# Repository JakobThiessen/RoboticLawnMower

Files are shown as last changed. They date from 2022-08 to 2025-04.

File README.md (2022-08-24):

# RoboticLawnMower
Rasenmähroboter in Eigenbau

## Konzept



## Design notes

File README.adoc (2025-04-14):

= RoboticLawnMower
:TOC:

== Projektbeschreibung
Rasenmähroboter in Eigenbau

== Konzept

static

== Projektübersicht

== Hardware
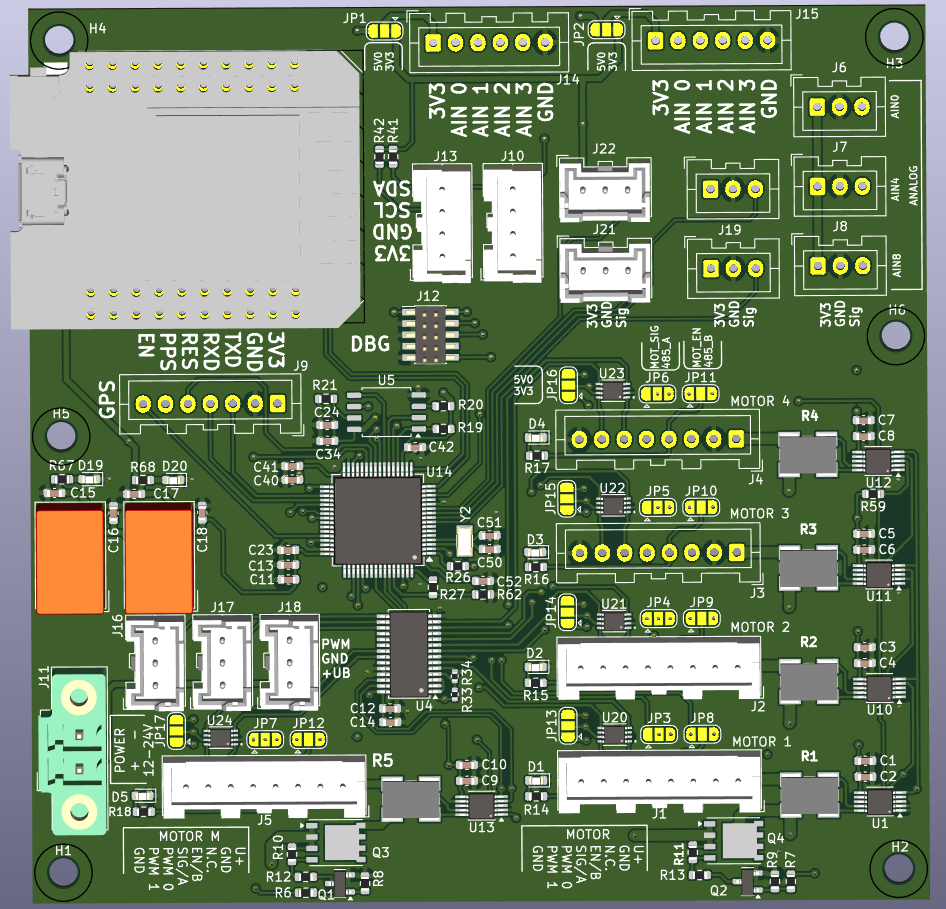
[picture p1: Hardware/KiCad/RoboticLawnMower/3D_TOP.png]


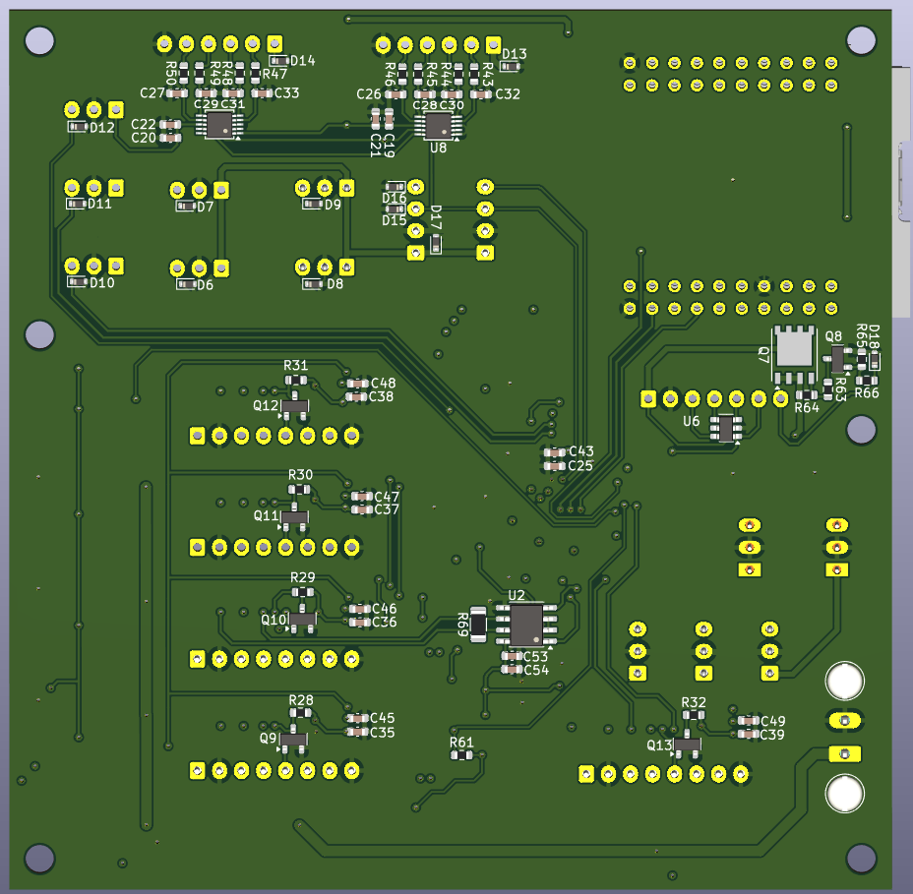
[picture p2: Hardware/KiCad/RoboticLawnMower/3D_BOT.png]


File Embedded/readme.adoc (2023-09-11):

[source,ruby]
----
static int8_t config_VL53L1(uint8_t chip_id)
{
	int8_t status = 0;
	
	  /* This function must to be called to initialize the sensor with the default setting  */
	  status = VL53L1X_SensorInit(chip_id);
	  /* Optional functions to be used to change the main ranging parameters according the application requirements to get the best ranging performances */
	  status = VL53L1X_SetDistanceMode(chip_id, 2); /* 1=short, 2=long */
	  status = VL53L1X_SetTimingBudgetInMs(chip_id, 100); /* in ms possible values [20, 50, 100, 200, 500] */
	  status = VL53L1X_SetInterMeasurementInMs(chip_id, 100); /* in ms, IM must be > = TB */
	  //  status = VL53L1X_SetOffset(chip_id,20); /* offset compensation in mm */
	  //  status = VL53L1X_SetROI(chip_id, 16, 16); /* minimum ROI 4,4 */
	  //	status = VL53L1X_CalibrateOffset(chip_id, 140, &offset); /* may take few second to perform the offset cal*/
	  //	status = VL53L1X_CalibrateXtalk(chip_id, 1000, &xtalk); /* may take few second to perform the xtalk cal */
//	  printf("VL53L1X Ultra Lite Driver Example running ...\n");
	  status = VL53L1X_StartRanging(chip_id);   /* This function has to be called to enable the ranging */	  
	  return status;
}
----

[source,c]
----
struct range_vl53l1
{
	uint16_t Distance;
	uint16_t SignalRate;
	uint16_t AmbientRate;
	uint16_t SpadNum;
	uint8_t RangeStatus;
};
----

[source,c]
int8_t getRange_VL53L1(uint8_t chip_id, struct range_vl53l1 *data)
{
	int8_t status;
	uint8_t dataReady = 0;
	while (dataReady == 0)
	{
		status = VL53L1X_CheckForDataReady(chip_id, &dataReady);
		//HAL_Delay(2);
	}
	dataReady = 0;
	status = VL53L1X_GetRangeStatus(chip_id, &data->RangeStatus);
	status = VL53L1X_GetDistance(chip_id, &data->Distance);
	status = VL53L1X_GetSignalRate(chip_id, &data->SignalRate);
	status = VL53L1X_GetAmbientRate(chip_id, &data->AmbientRate);
	status = VL53L1X_GetSpadNb(chip_id, &data->SpadNum);
	status = VL53L1X_ClearInterrupt(chip_id); /* clear interrupt has to be called to enable next interrupt*/
//	printf("%u, %u, %u, %u, %u\n", data->RangeStatus, data->Distance, data->SignalRate, data->AmbientRate, data->SpadNum);
	return status;
}
----

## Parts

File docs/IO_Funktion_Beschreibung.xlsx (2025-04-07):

 | Bezeichnung | Art | Count | Beschreibung
Sicherheit
 | NotAus | GPIO | 1 | NotAus-Schalter | GPIO
 | Kollision | GPIO | 3 | Kollision Sensor | GPIO
 | Abstandssensor | ADC | 3 | US oder TOF IR/Laser | ?
Motor
 | PCA92…. PWM | I2C - 1 | 2 | evtl. Ersatz für GPIO
 | Motor R |  |  | Motor Rechts
 | EN | GPIO | 0 | Enable Pin | GPIO PWR EN
 | Sig | Counter | 1 | Input Counter | CTR
 | V/R | GPIO | 1 | Vorwärts/Rückwärts
 | VEL | PWM | 0 | Geschwindigkeit | TIM
 | Motor L |  |  | Motor Links
 | EN | GPIO | 0 | Enable Pin | GPIO PWR EN
 | Sig | Counter | 1 | Input Counter | CTR
 | V/R | GPIO | 1 | Vorwärts/Rückwärts
 | VEL | PWM | 0 | Geschwindigkeit | TIM
 | Motor R |  |  | Motor Rechts
 | EN | GPIO |  | Enable Pin | GPIO PWR EN
 | Sig | Counter | 1 | Input Counter | CTR
 | V/R | GPIO | 1 | Vorwärts/Rückwärts
 | VEL | PWM | 0 | Geschwindigkeit | TIM
 | Motor L |  |  | Motor Links
 | EN | GPIO |  | Enable Pin | GPIO PWR EN
 | Sig | Counter | 1 | Input Counter | CTR
 | V/R | GPIO | 1 | Vorwärts/Rückwärts
 | VEL | PWM | 0 | Geschwindigkeit | TIM
 | Motor M |  |  | Motor Schneidewerk
 | EN | GPIO | 0 | Enable Pin | GPIO PWR EN
 | Sig | Counter | 1 | Input Counter | CTR
 | V/R | GPIO | 1 | Vorwärts/Rückwärts
 | VEL | PWM | 0 | Geschwindigkeit | TIM
 | INA228 | I2C - 1 |  | Strom, Spannung für Motor R
 | alarm | GPIO | 1 | Trigger level für Strom (Interrupt) | GPIO - OpenDrain
 | INA228 | I2C - 1 |  | Strom, Spannung für Motor L
 | alarm | GPIO |  | Trigger level für Strom (Interrupt)
 | INA228 | I2C - 1 |  | Strom, Spannung für Motor M
 | alarm | GPIO | 1 | Trigger level für Strom (Interrupt) | GPIO - OpenDrain
 | FET-Disable | GPIO | 1 | Motorspannung abschalten bei Fehler | GPIO
 | FET-Disable | GPIO | 1 | evtl Mähwerk abschalten | GPIO
Sensor
 | Licht | PCA92…. PWM | 1 | Licht
 | Bremslicht | PCA92…. PWM | 1 | Licht
 | Kompass | I2C - 0 | 2 | Kompass (eCompass)
 | BME280 | I2C - 0 |  | Temp, Druck, Luftfeuchtigkeit
 | BMI160 | I2C - 0 |  | Beschleunigungs- und Drehratensensor
 | Licht | I2C - 3 | 2 | Lichtsensor
 | PIR GridEye | I2C - 3 |  | 8X8 PIR sensor
 | GPS | UART 0 | 2 | GPS-Ortung
 |  |  | 1 | GPS EN
 | Schleife | ADC | 3 | Schleifen-Sensor
Komfort
 | ESP32 | UART 1 | 5 | WLAN/BT Kommunikation (Evtl. Kamera)
 | Display | I2C - 3
 | Tastatur | I2C - 3
 | Mähwerk |  |  | Höhenverstellung Mähwerk
 | FRAM | SPI | 4 | Speicher für Konfiguration / Karte
 | WS2128 | GPIO |  | Lichteffekte
 |  |  | 44
STM32H573 |  |  | 49

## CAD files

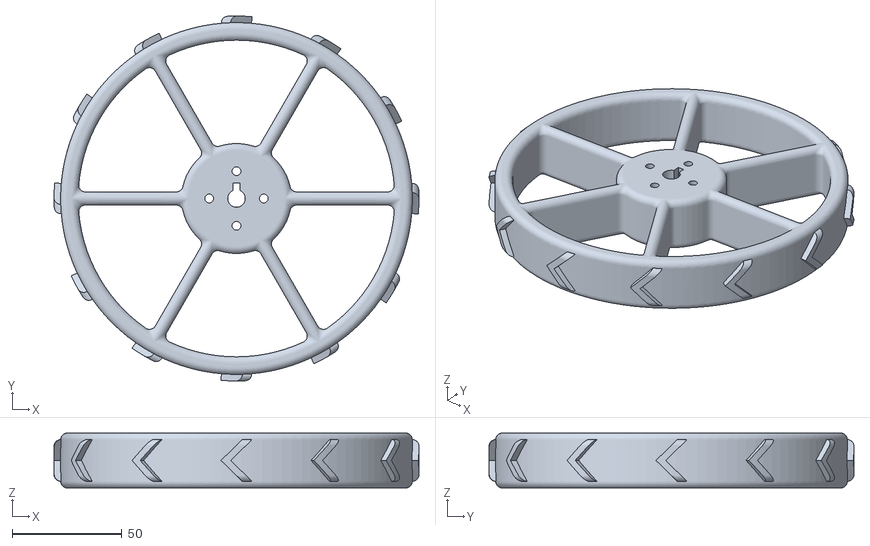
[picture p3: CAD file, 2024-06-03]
3d-models/rearWheel_6xSpoke.stl
166.0 x 166.0 x 25.0

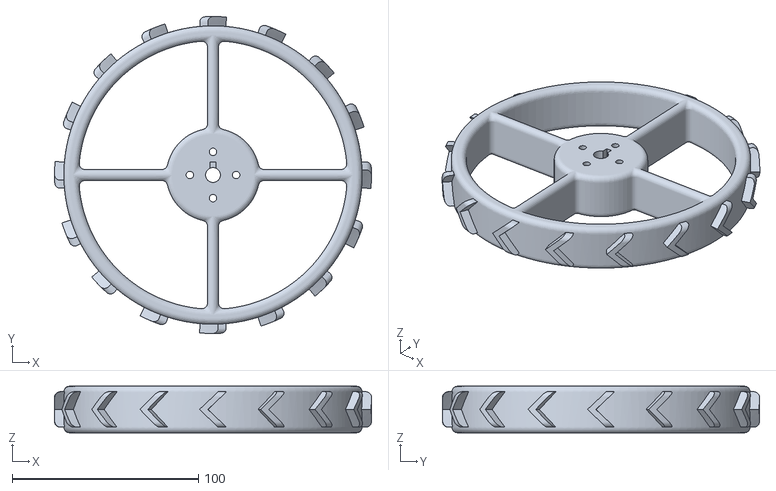
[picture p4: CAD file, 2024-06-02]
3d-models/rearWheel.stl
170.0 x 170.0 x 25.0

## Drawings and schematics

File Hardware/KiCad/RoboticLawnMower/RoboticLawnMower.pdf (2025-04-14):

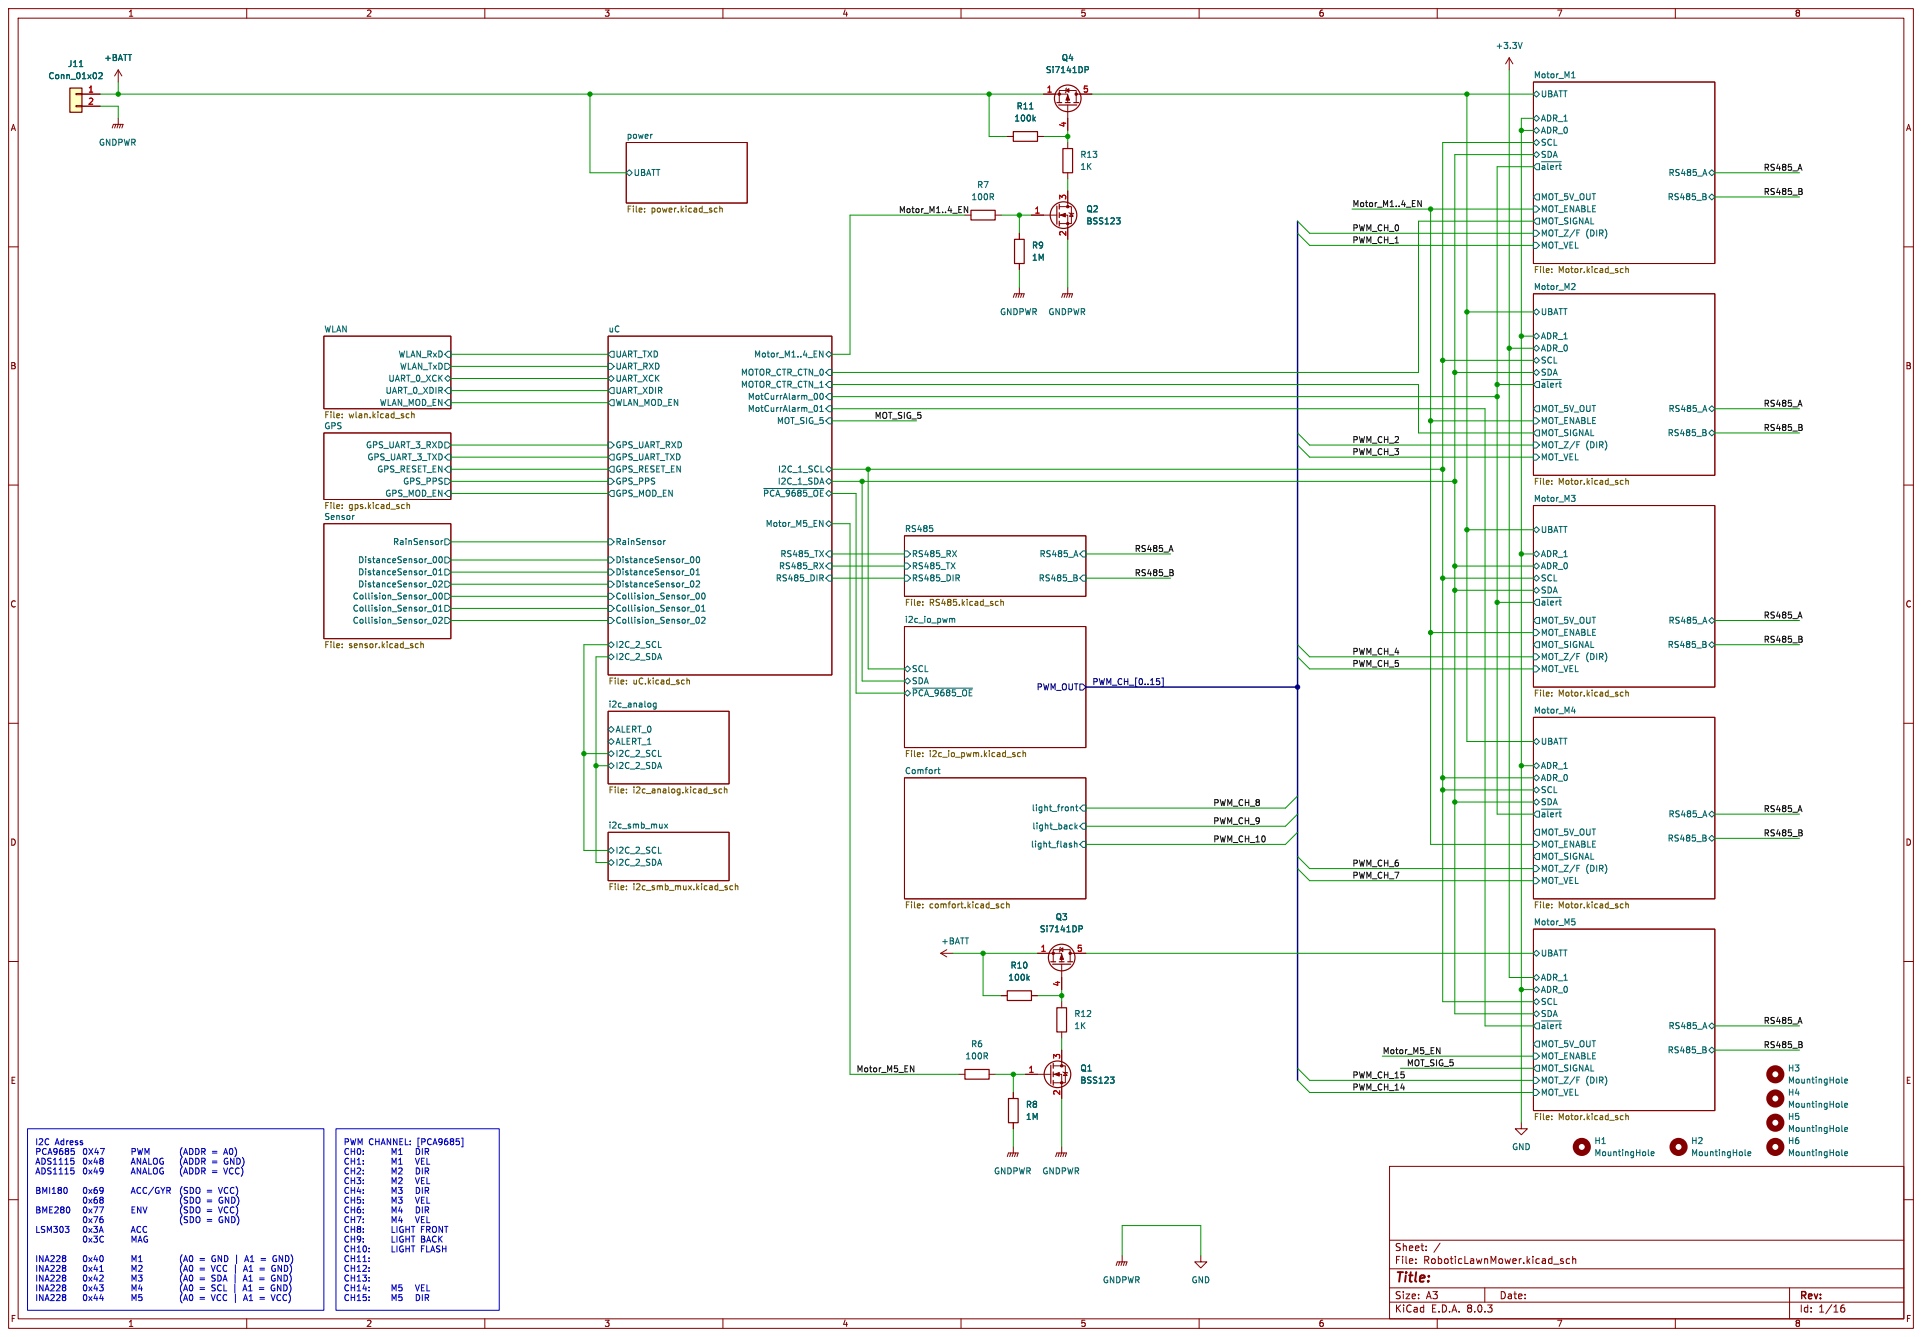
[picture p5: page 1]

PWM_CH_0 PWM_CH_1
UBATT ADR_1 MOT_VEL SCL MOT_Z/F (DIR) ADR_0 MOT_5V_OUT SDA MOT_SIGNAL MOT_ENABLE

PWM_CH_6

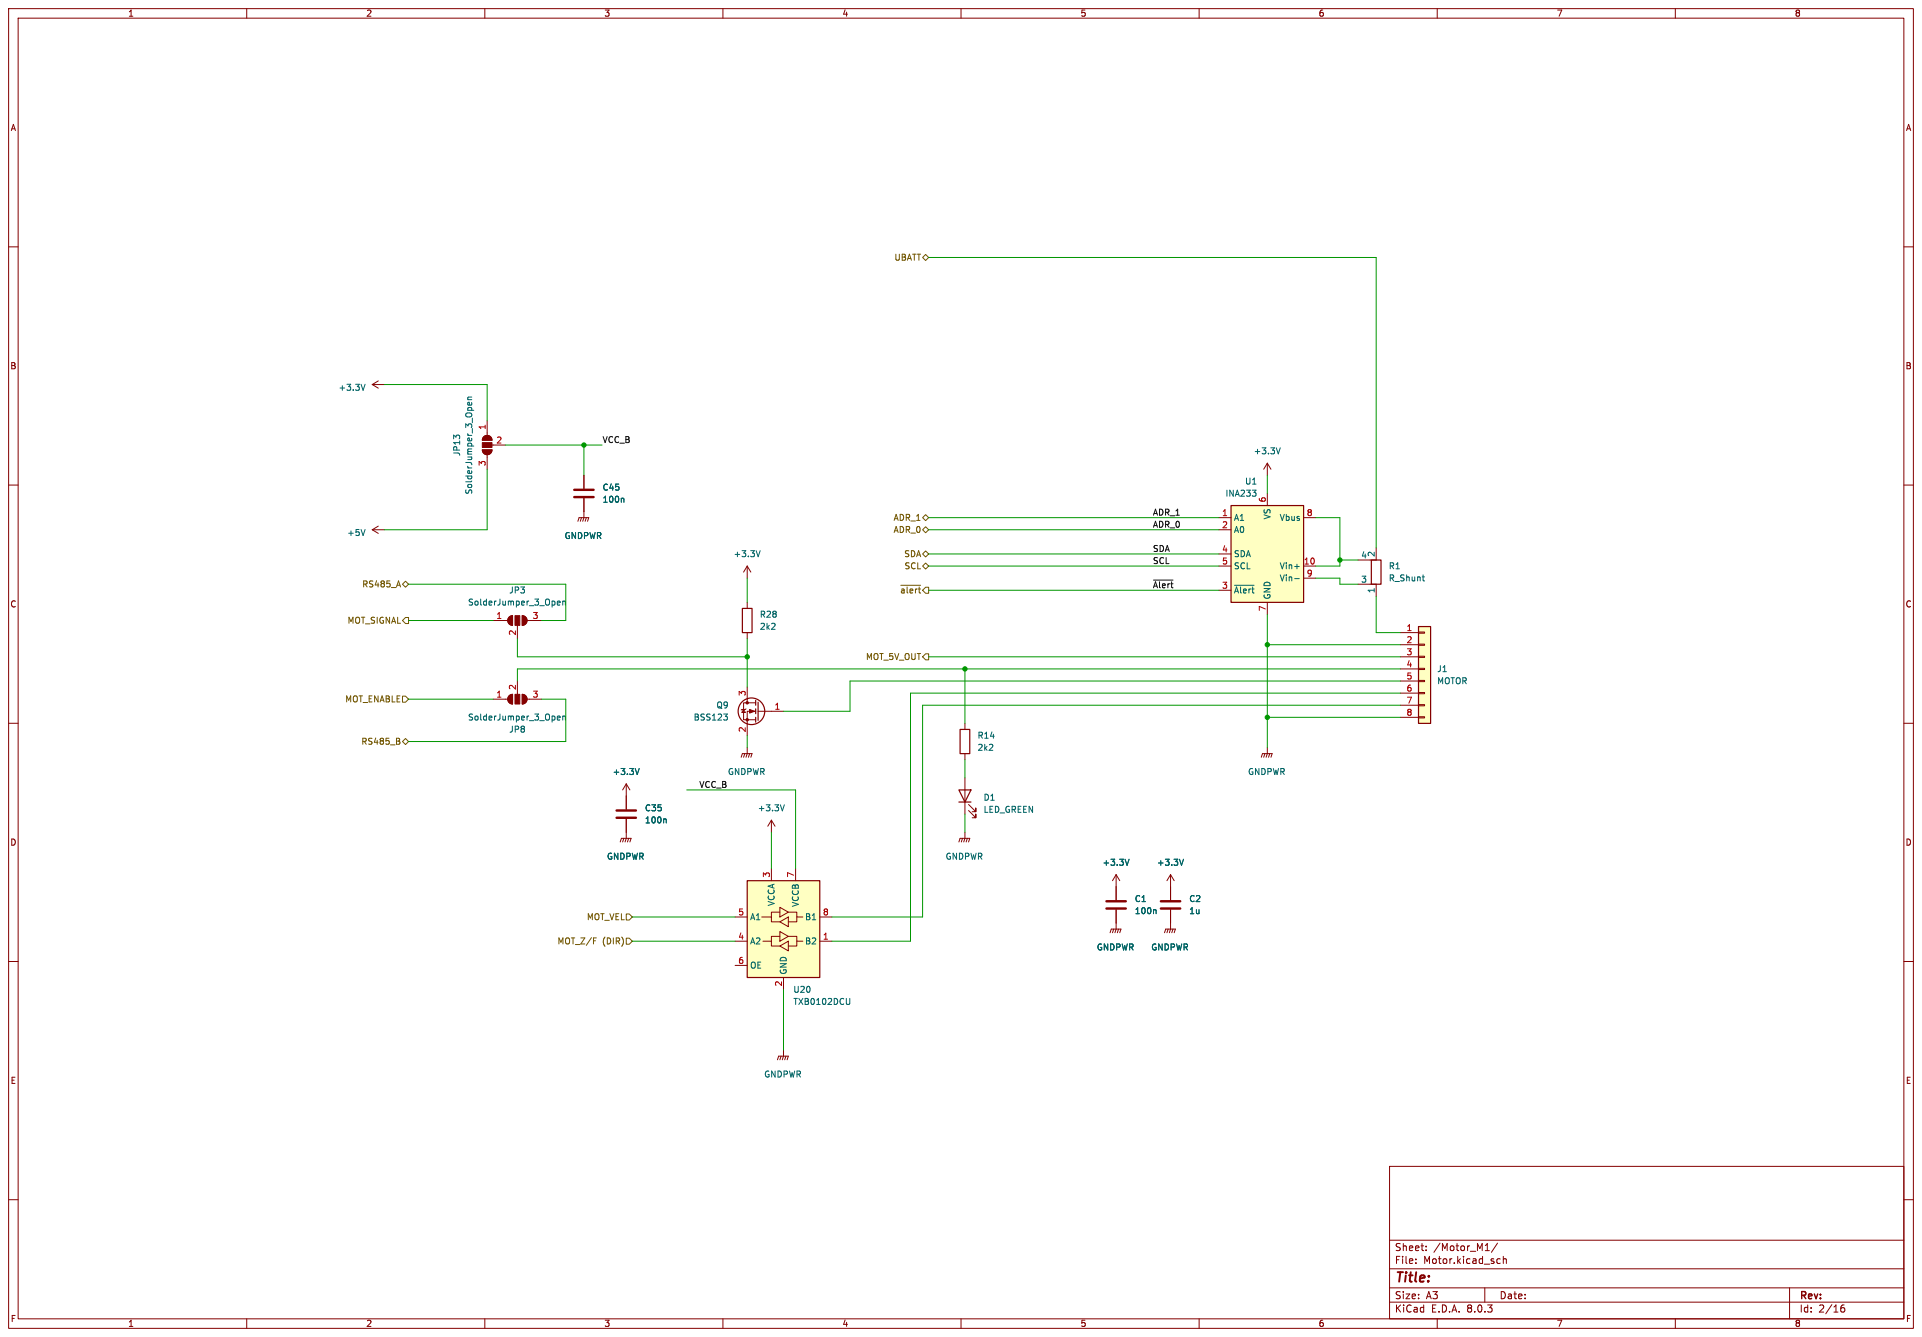
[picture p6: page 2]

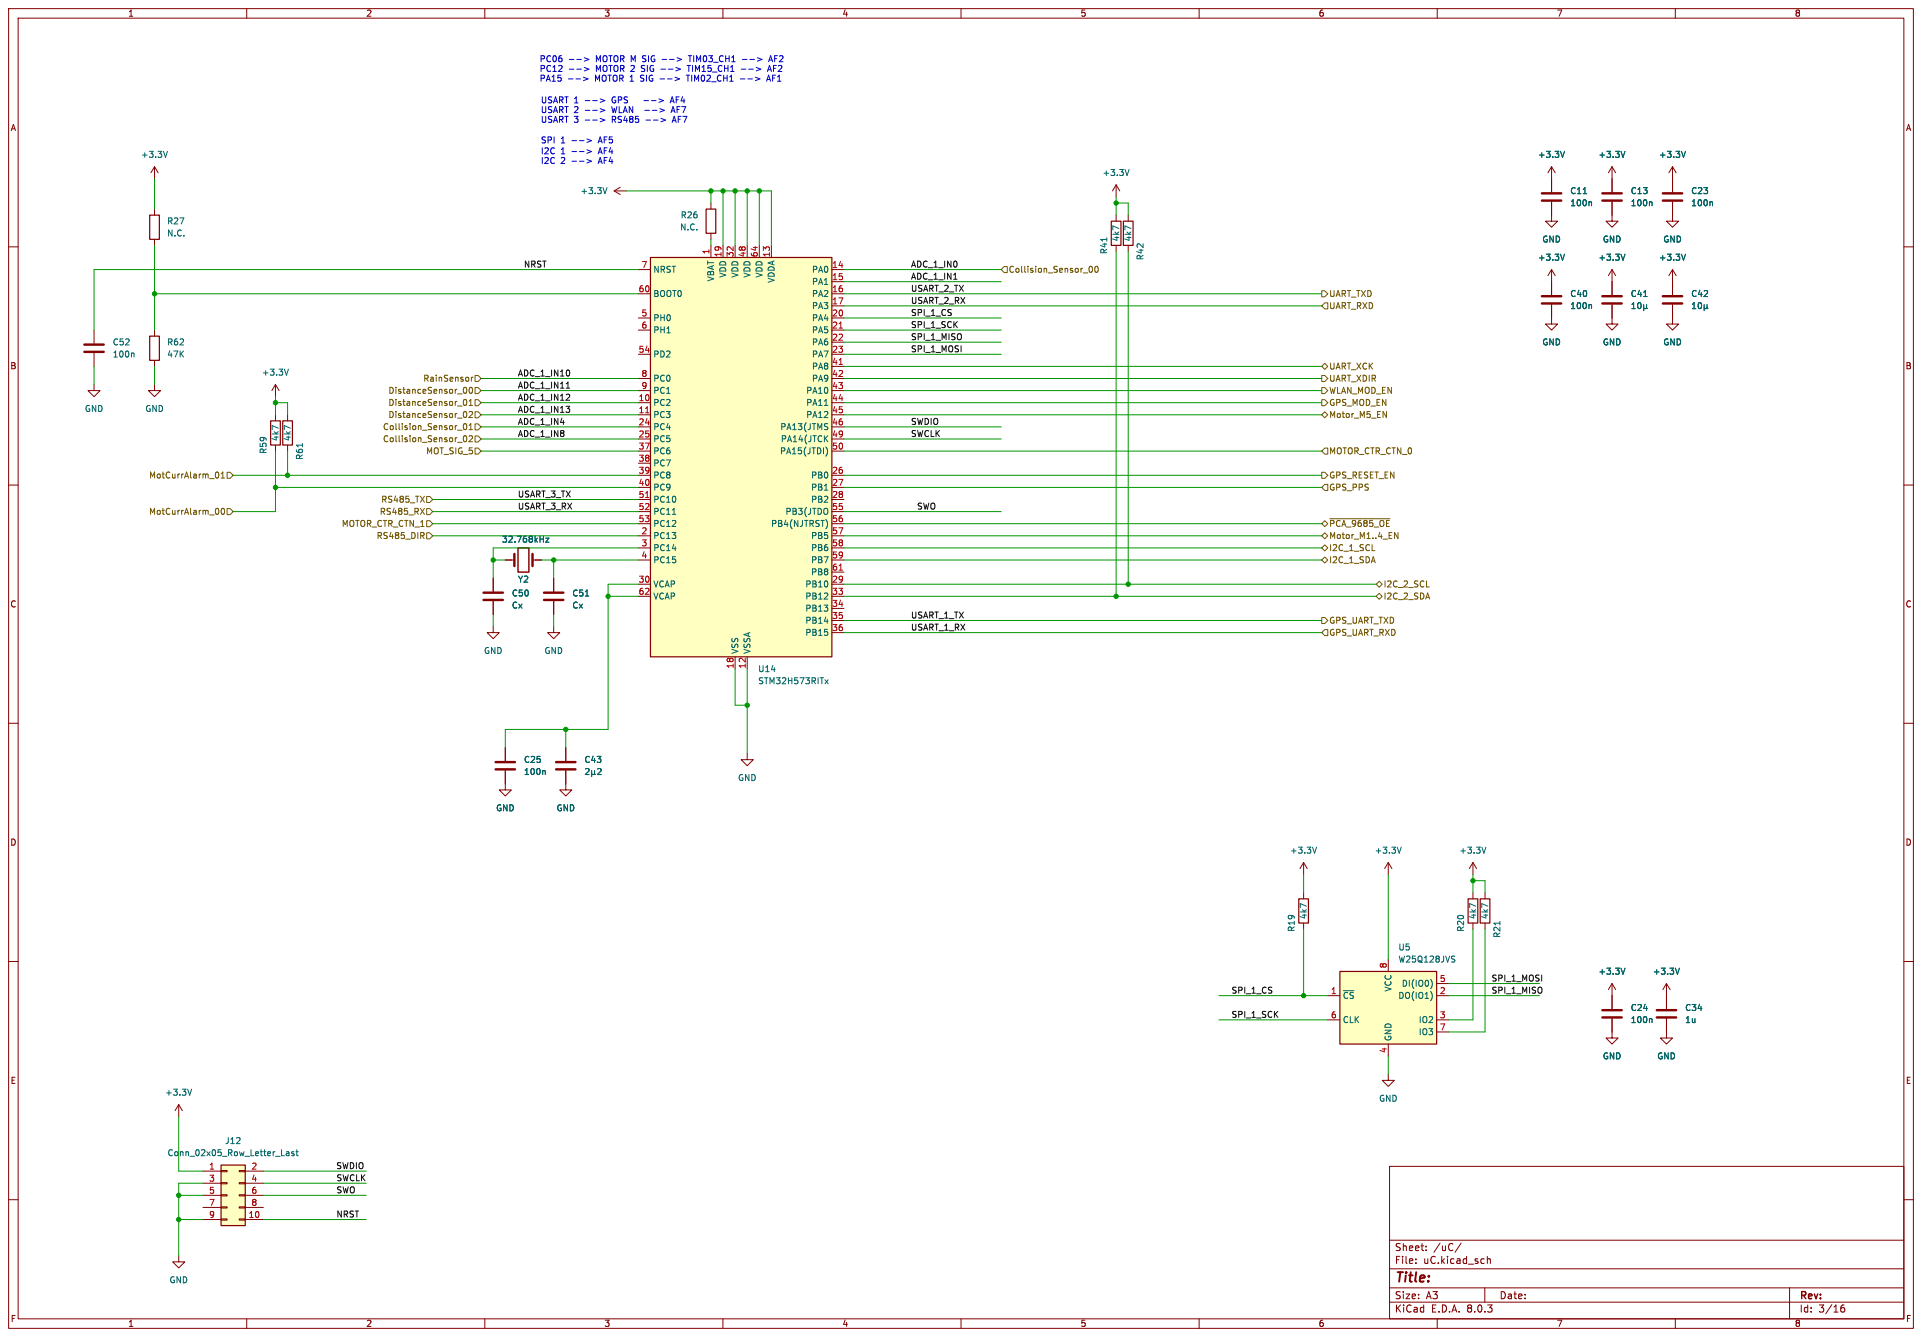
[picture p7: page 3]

1 PC2 10 PC3 11 VSSA 12 VDDA 13 PA0 14 PA1 15 PA2 16 PA3 17 VSS 18 VDD 19 PC13 2 PA4 20 PA5 21 PA6 22 PA7 23 PC4 24 PC5 25 PB0 26 PB1 27 PB2 28 PB10 29 PC14 3 VCAP 30 VDD 32 PB12 33 PB13 34 PB14 35 PB15 36 PC6 37 PC7 38 PC8 39 PC15 4 PC9 40 PA8 41 PA9 42 PA10 43 PA11 44 PA12 45 PA13(JTMS 46 VDD 48

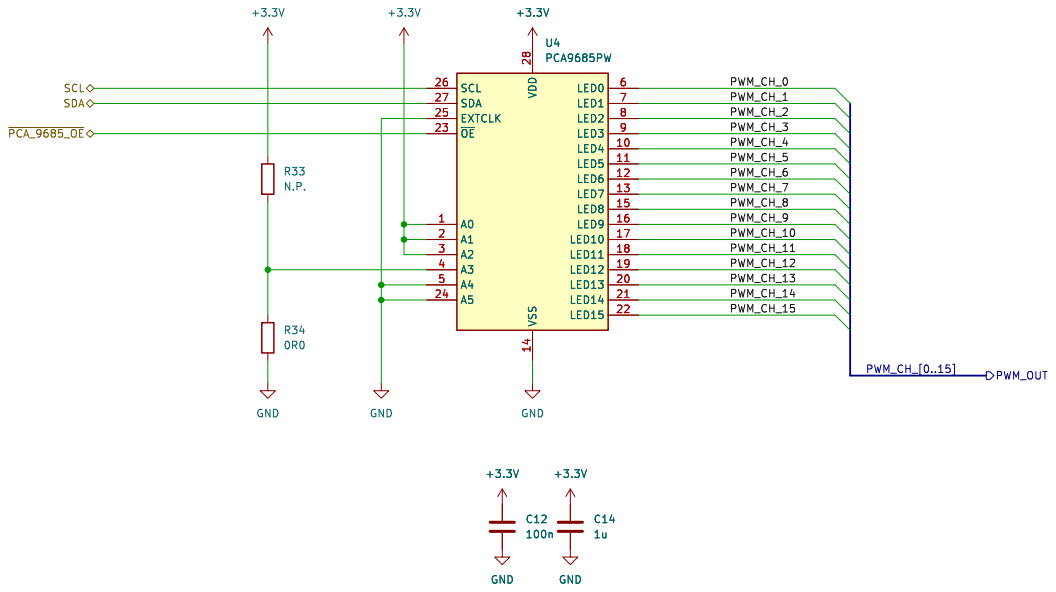
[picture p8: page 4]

Id: 5/16 Title: File: i2c_io_pwm.kicad_sch Sheet: /i2c_io_pwm/

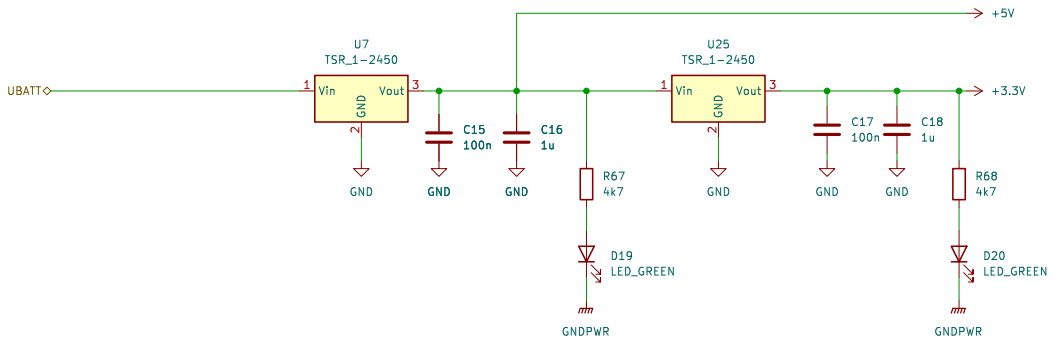
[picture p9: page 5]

2 Vout 3 U25 TSR_1-2450 GND GND GND

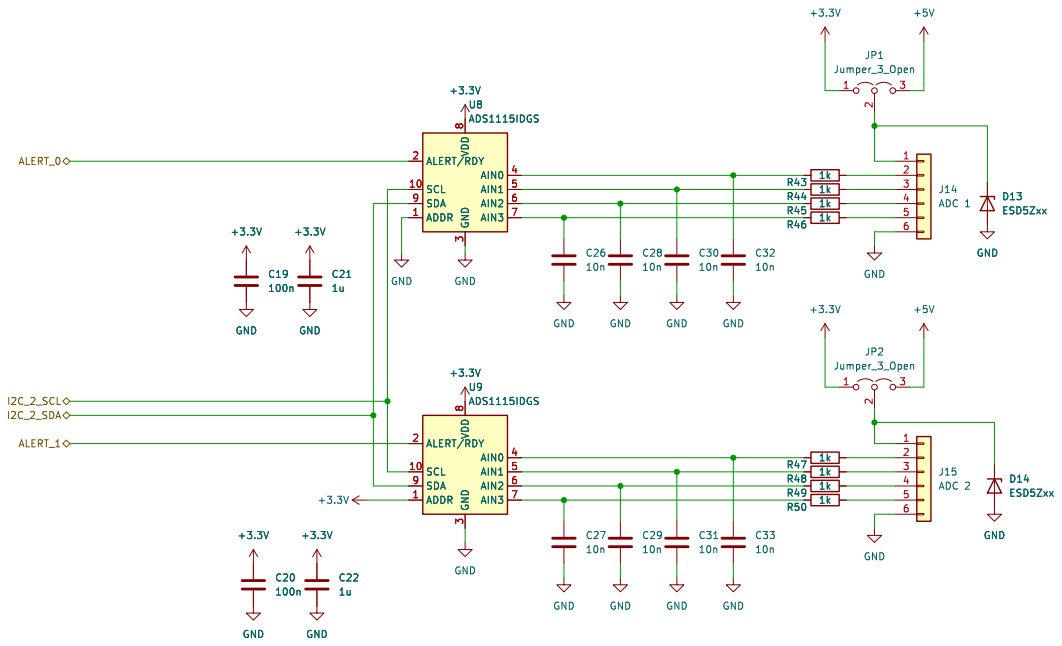
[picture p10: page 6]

Id: 8/16 Title: File: i2c_analog.kicad_sch Sheet: /i2c_analog/

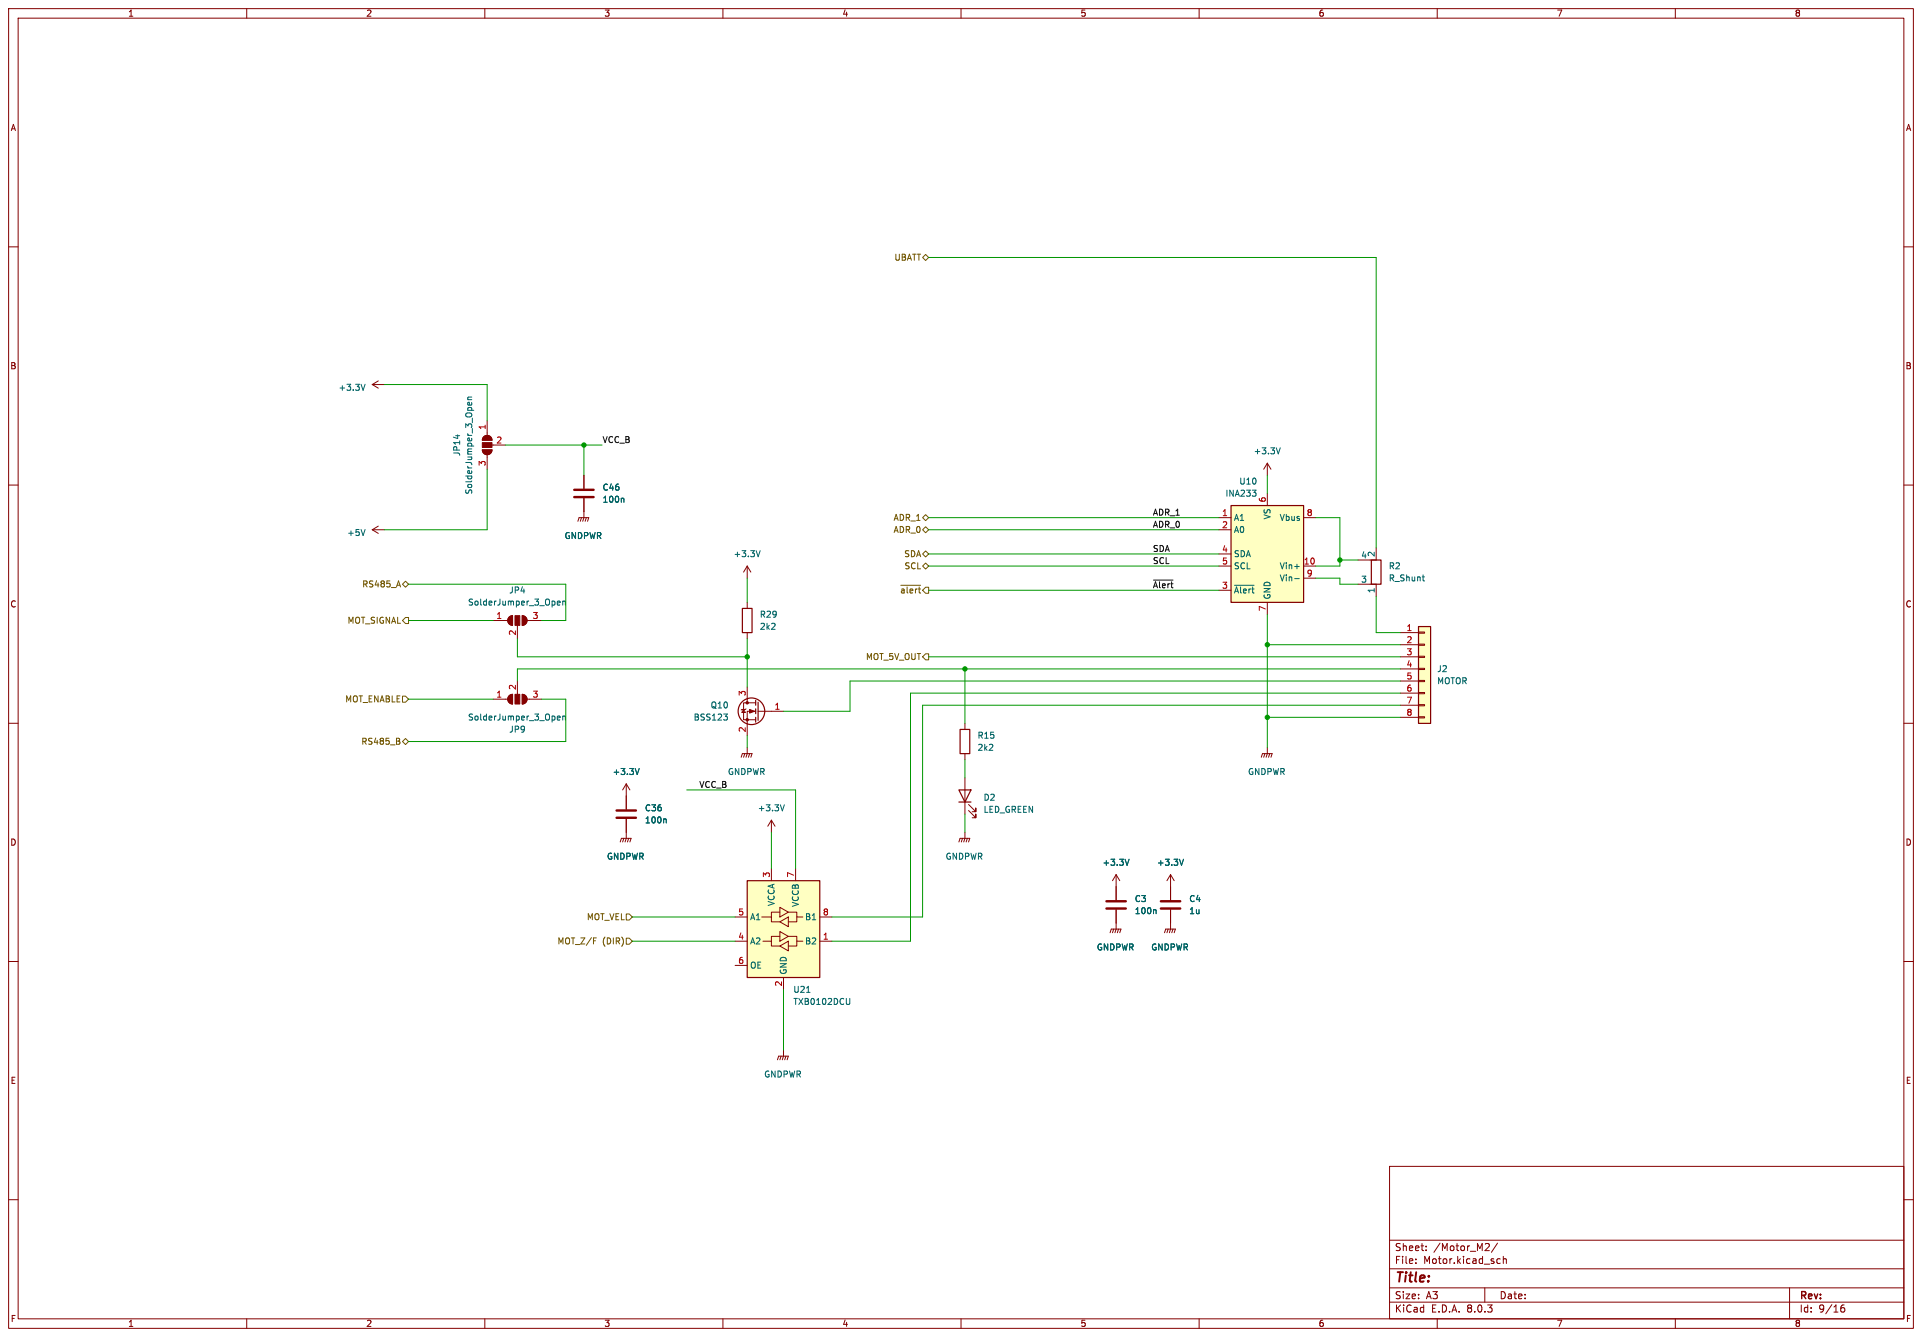
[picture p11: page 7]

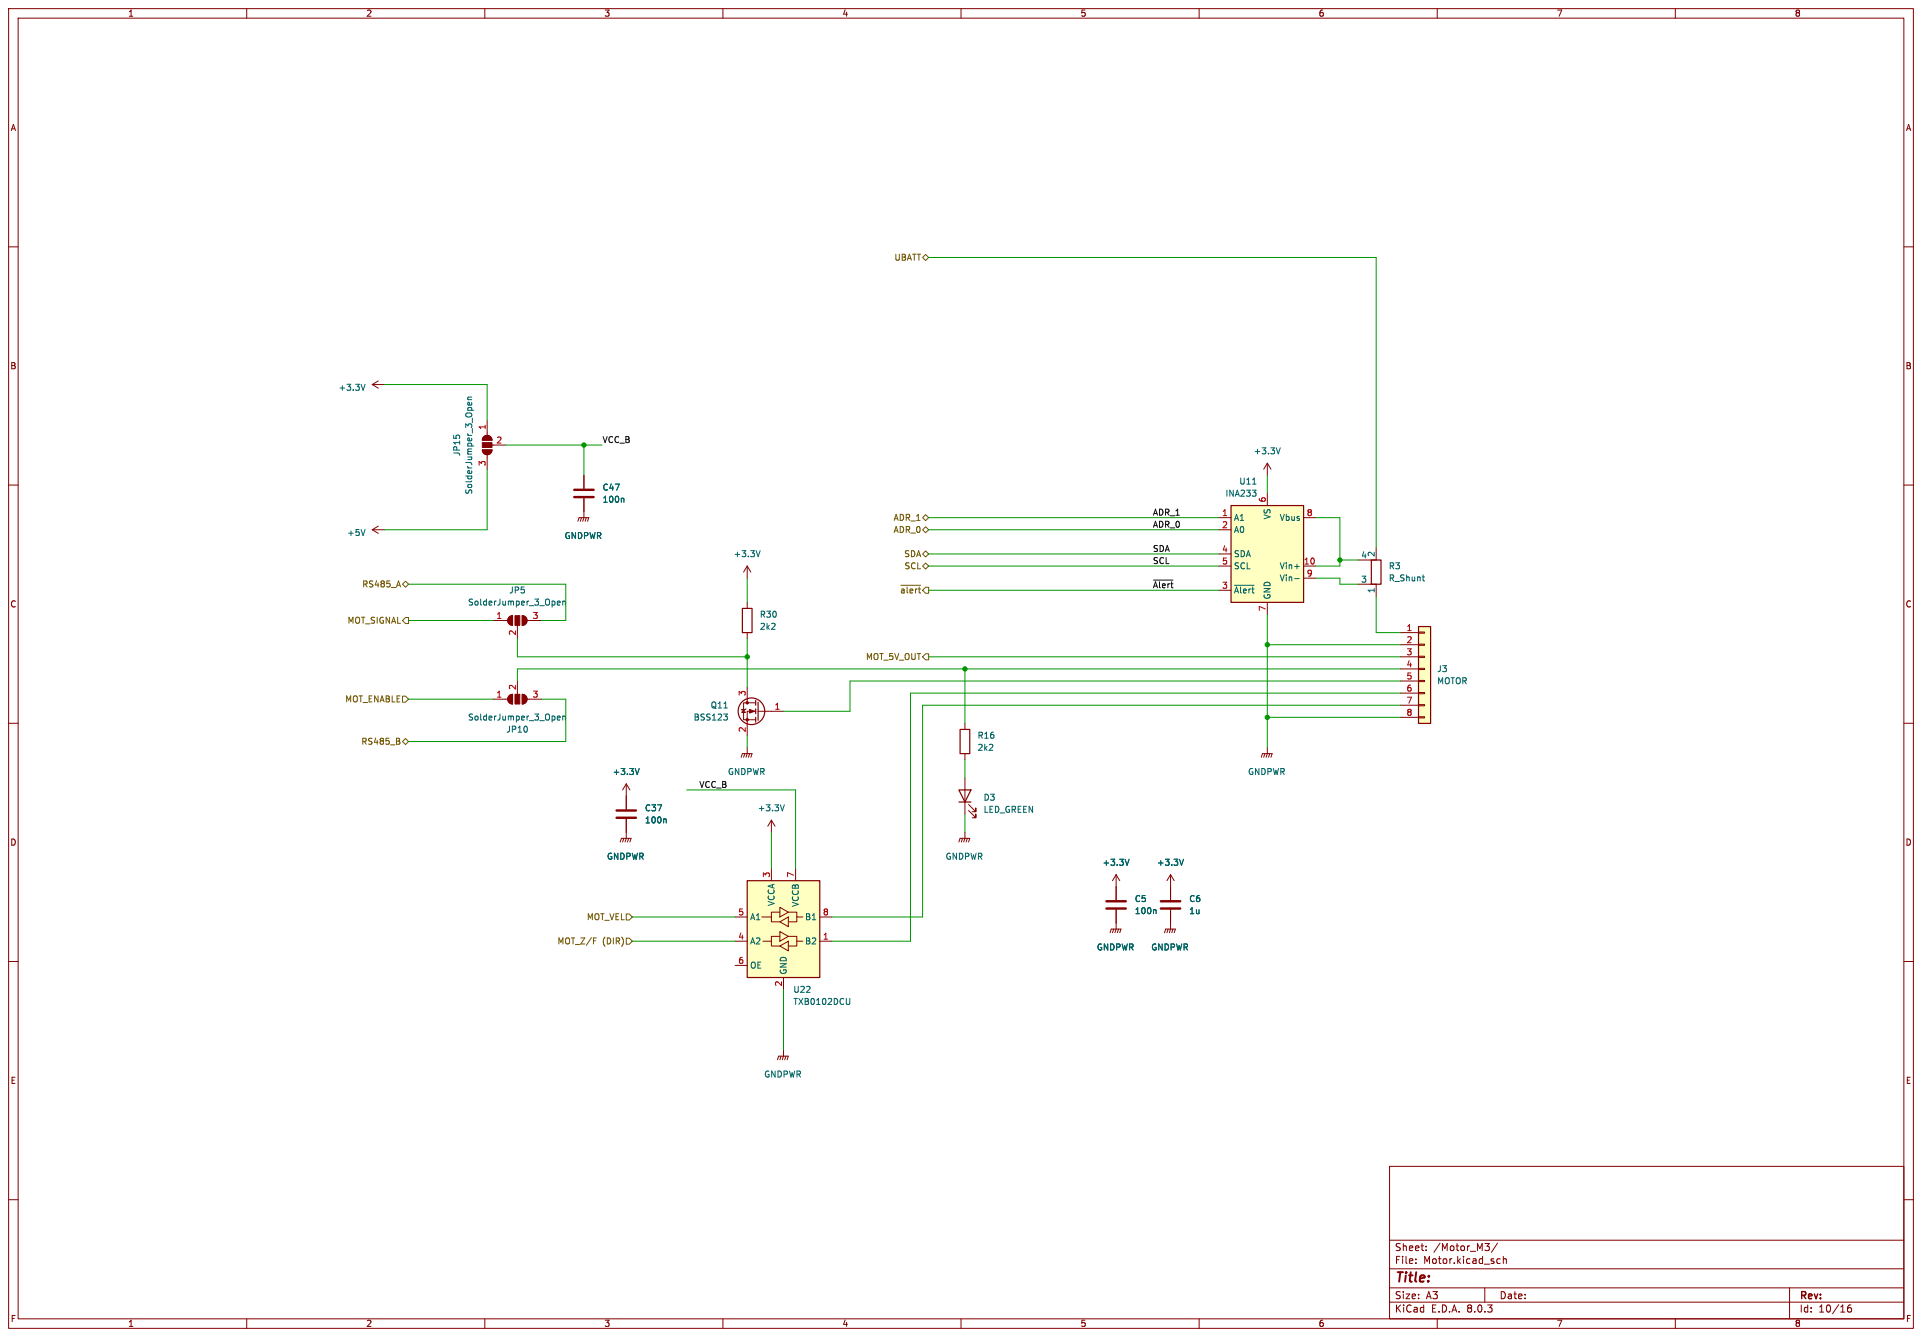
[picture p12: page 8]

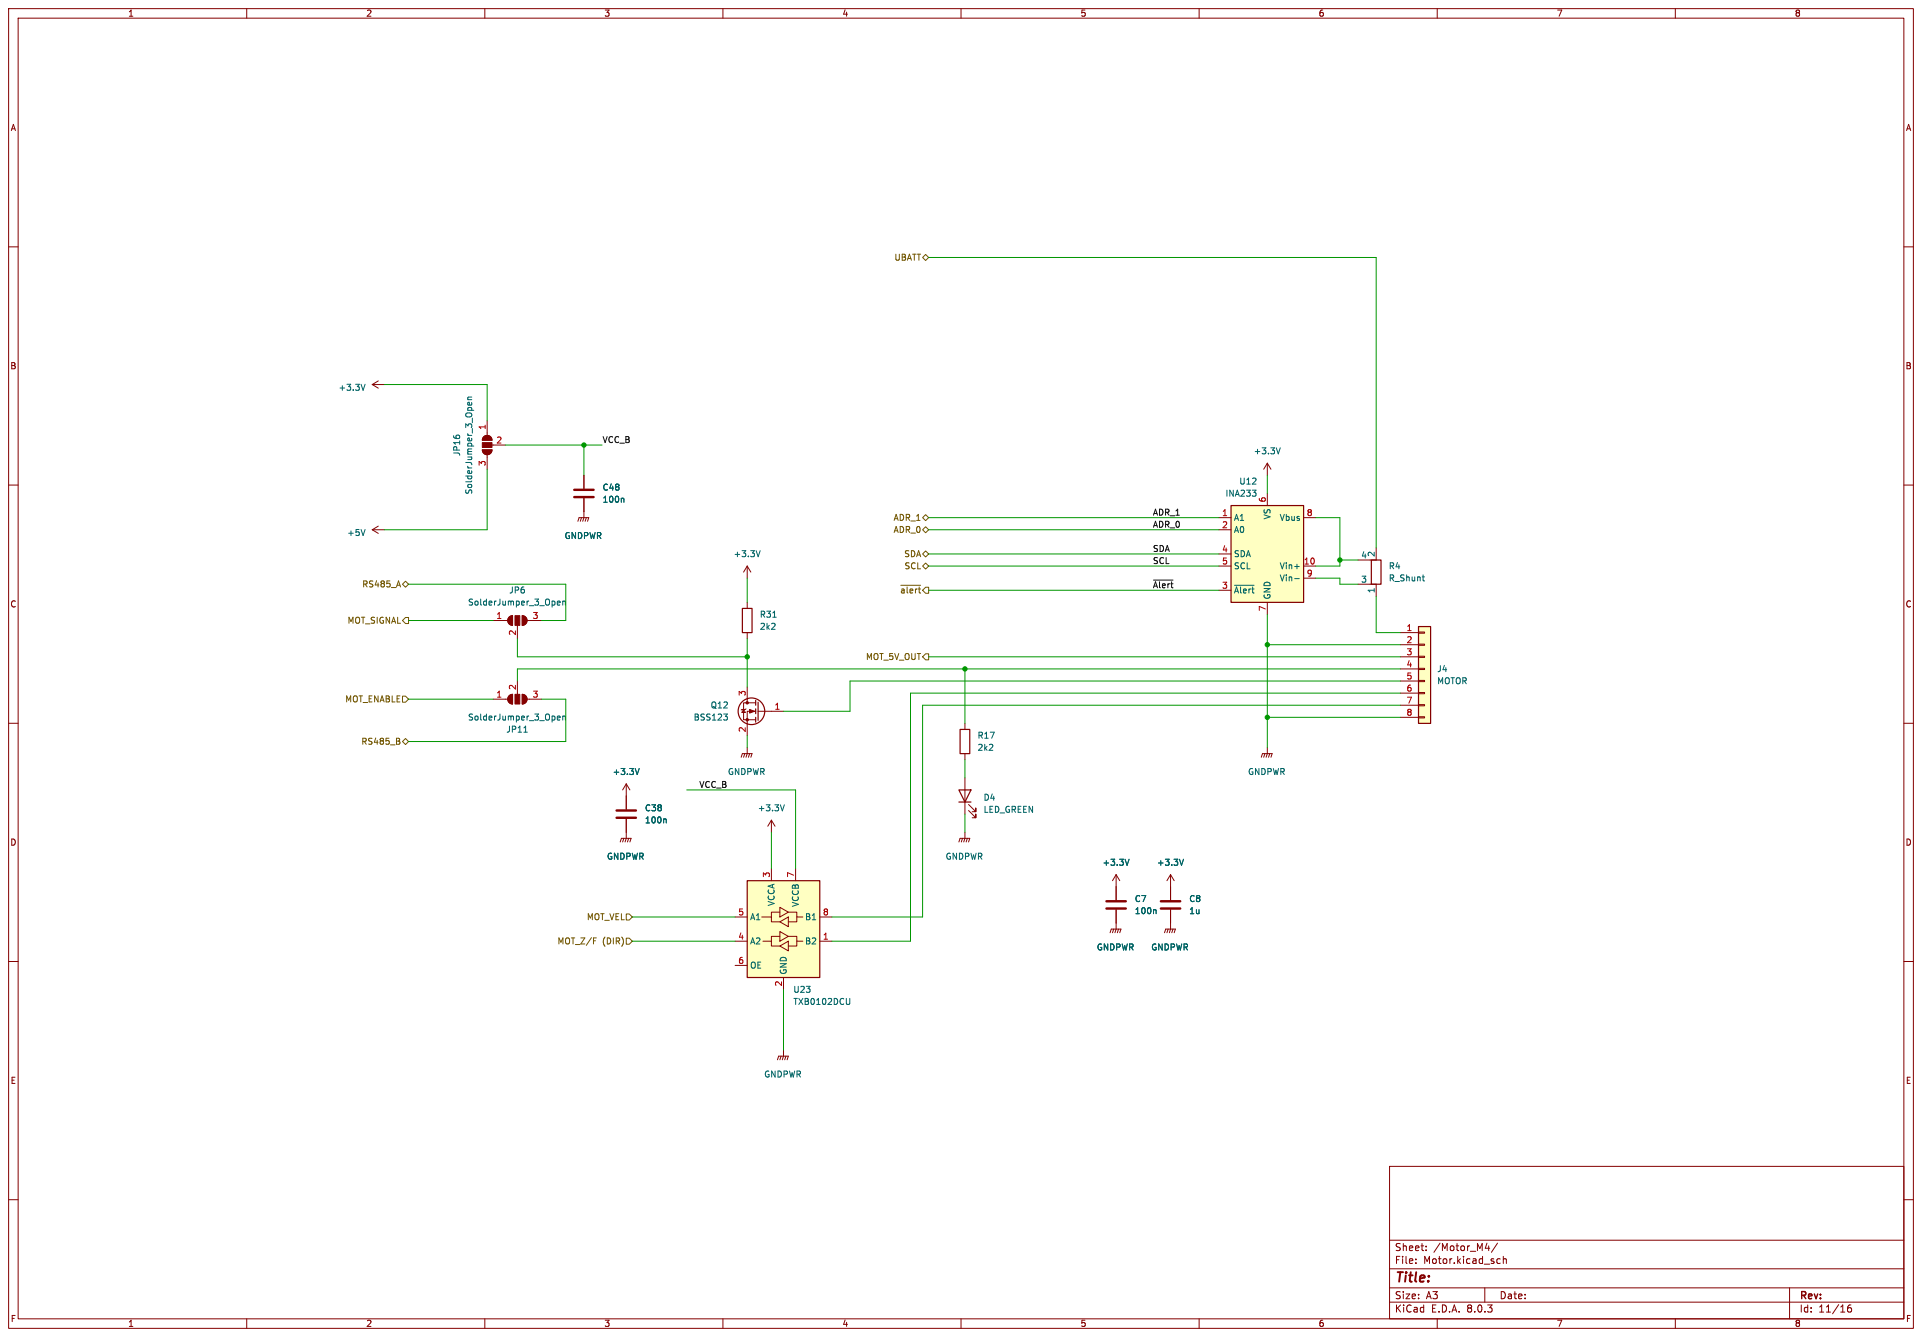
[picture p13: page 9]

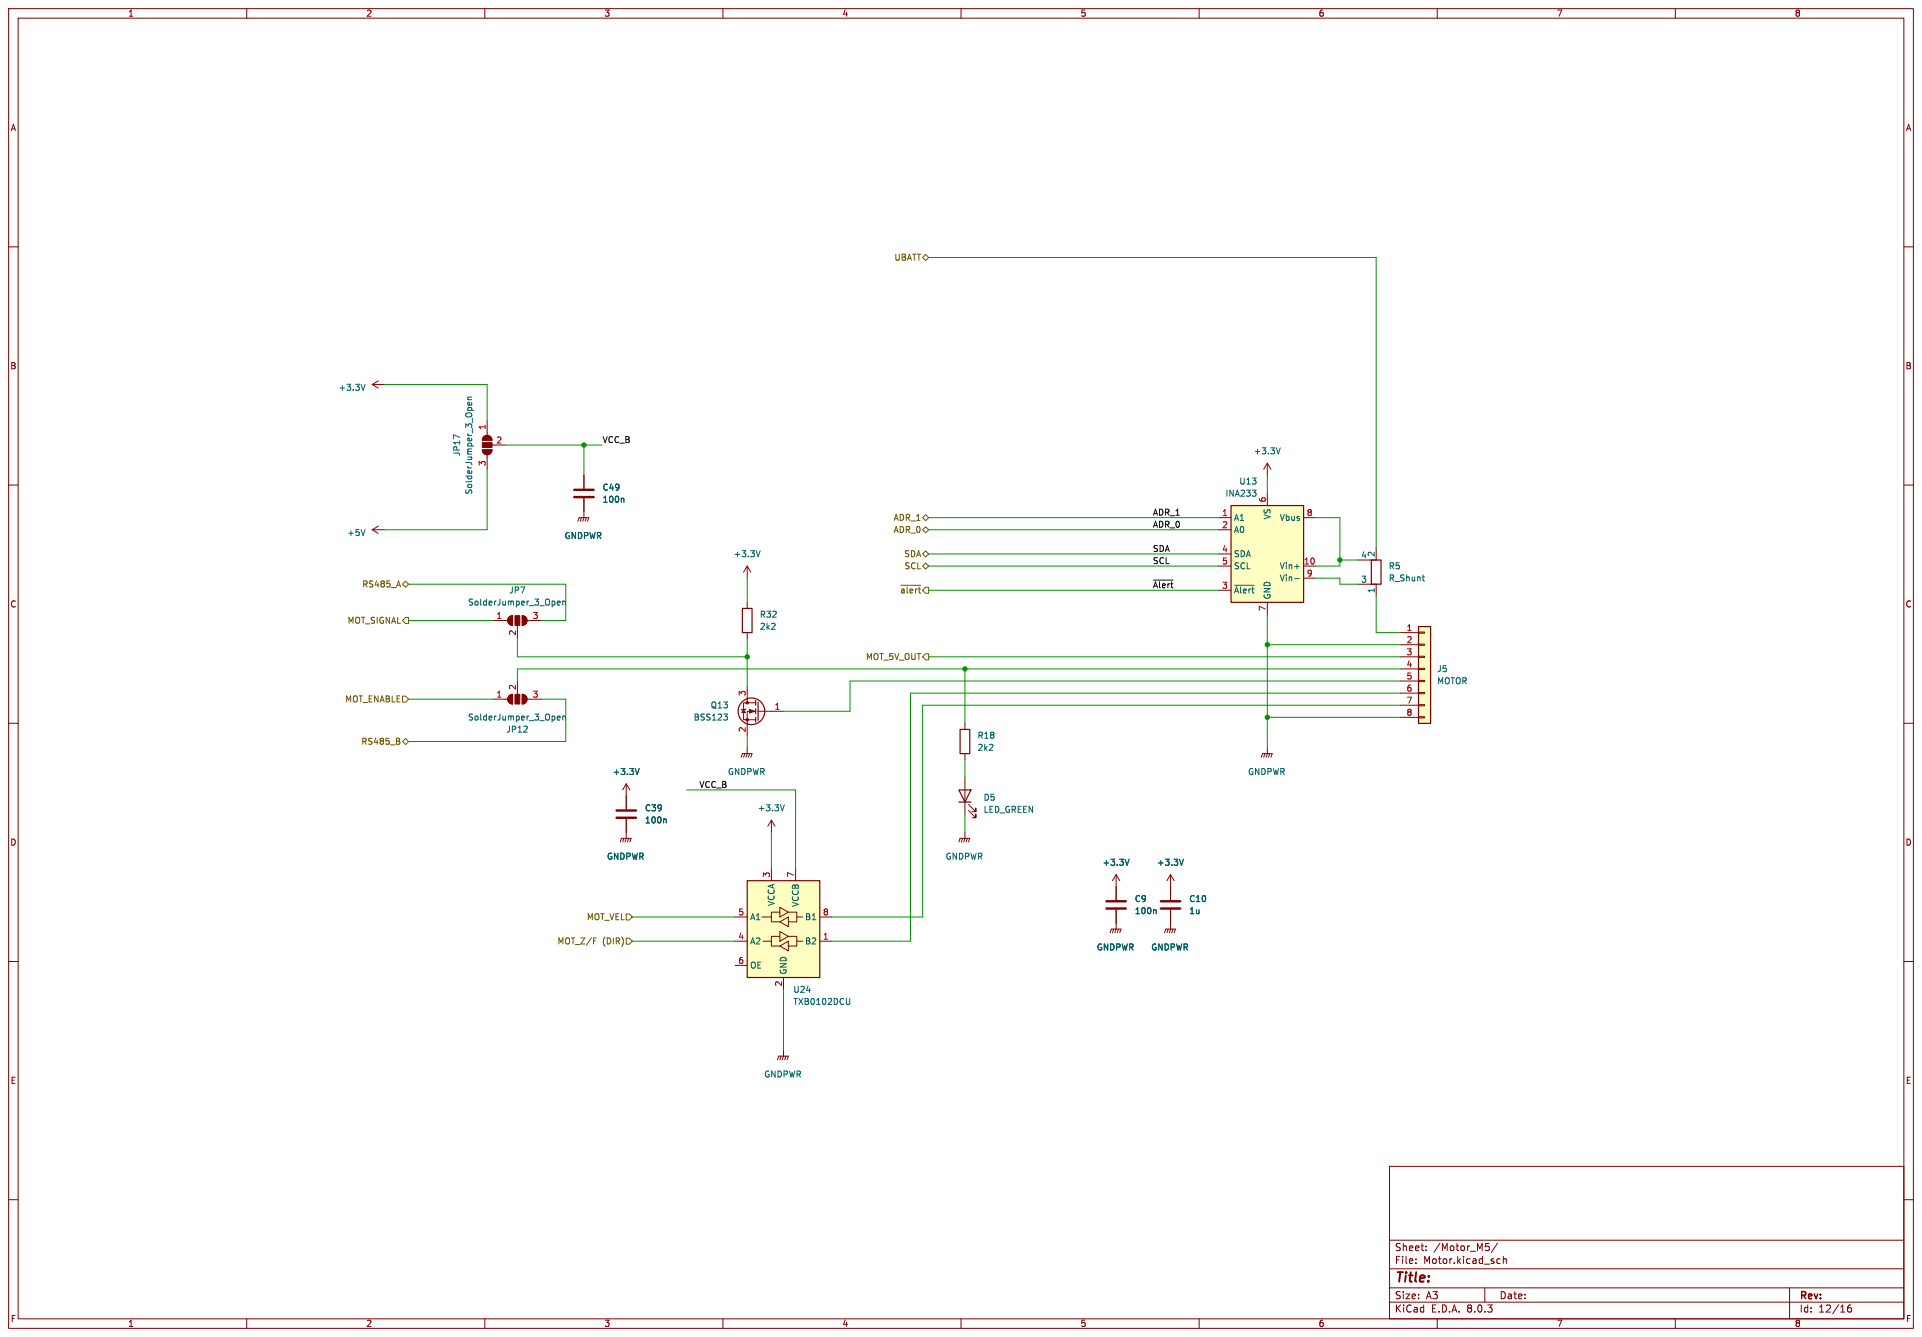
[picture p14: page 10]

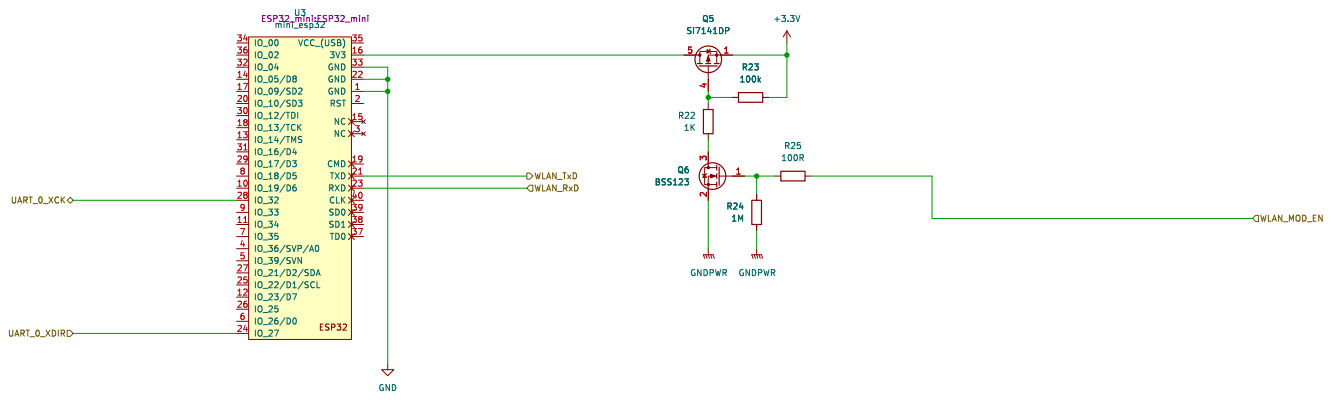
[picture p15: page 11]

Id: 13/16 Title: File: wlan.kicad_sch Sheet: /WLAN/

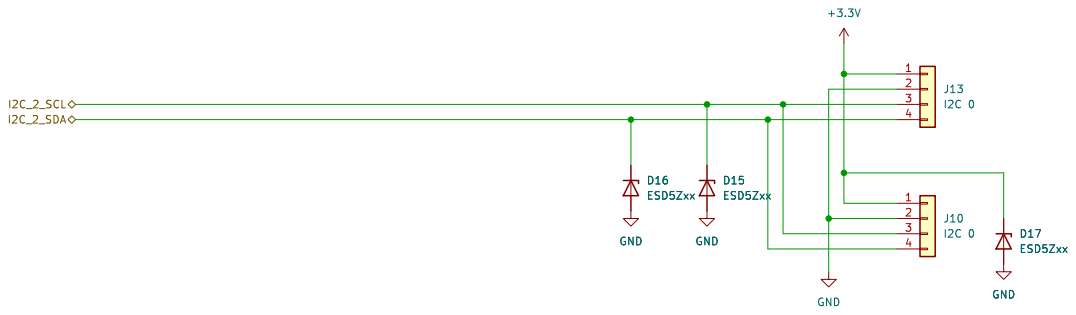
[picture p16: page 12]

Id: 13/16 Title: File: i2c_smb_mux.kicad_sch Sheet: /i2c_smb_mux/


Id: 14/16 Title: File: comfort.kicad_sch Sheet: /Comfort/ +BATT



Id: 16/16 Title: File: gps.kicad_sch Sheet: /GPS/


Id: 16/16 Title: File: RS485.kicad_sch Sheet: /RS485/

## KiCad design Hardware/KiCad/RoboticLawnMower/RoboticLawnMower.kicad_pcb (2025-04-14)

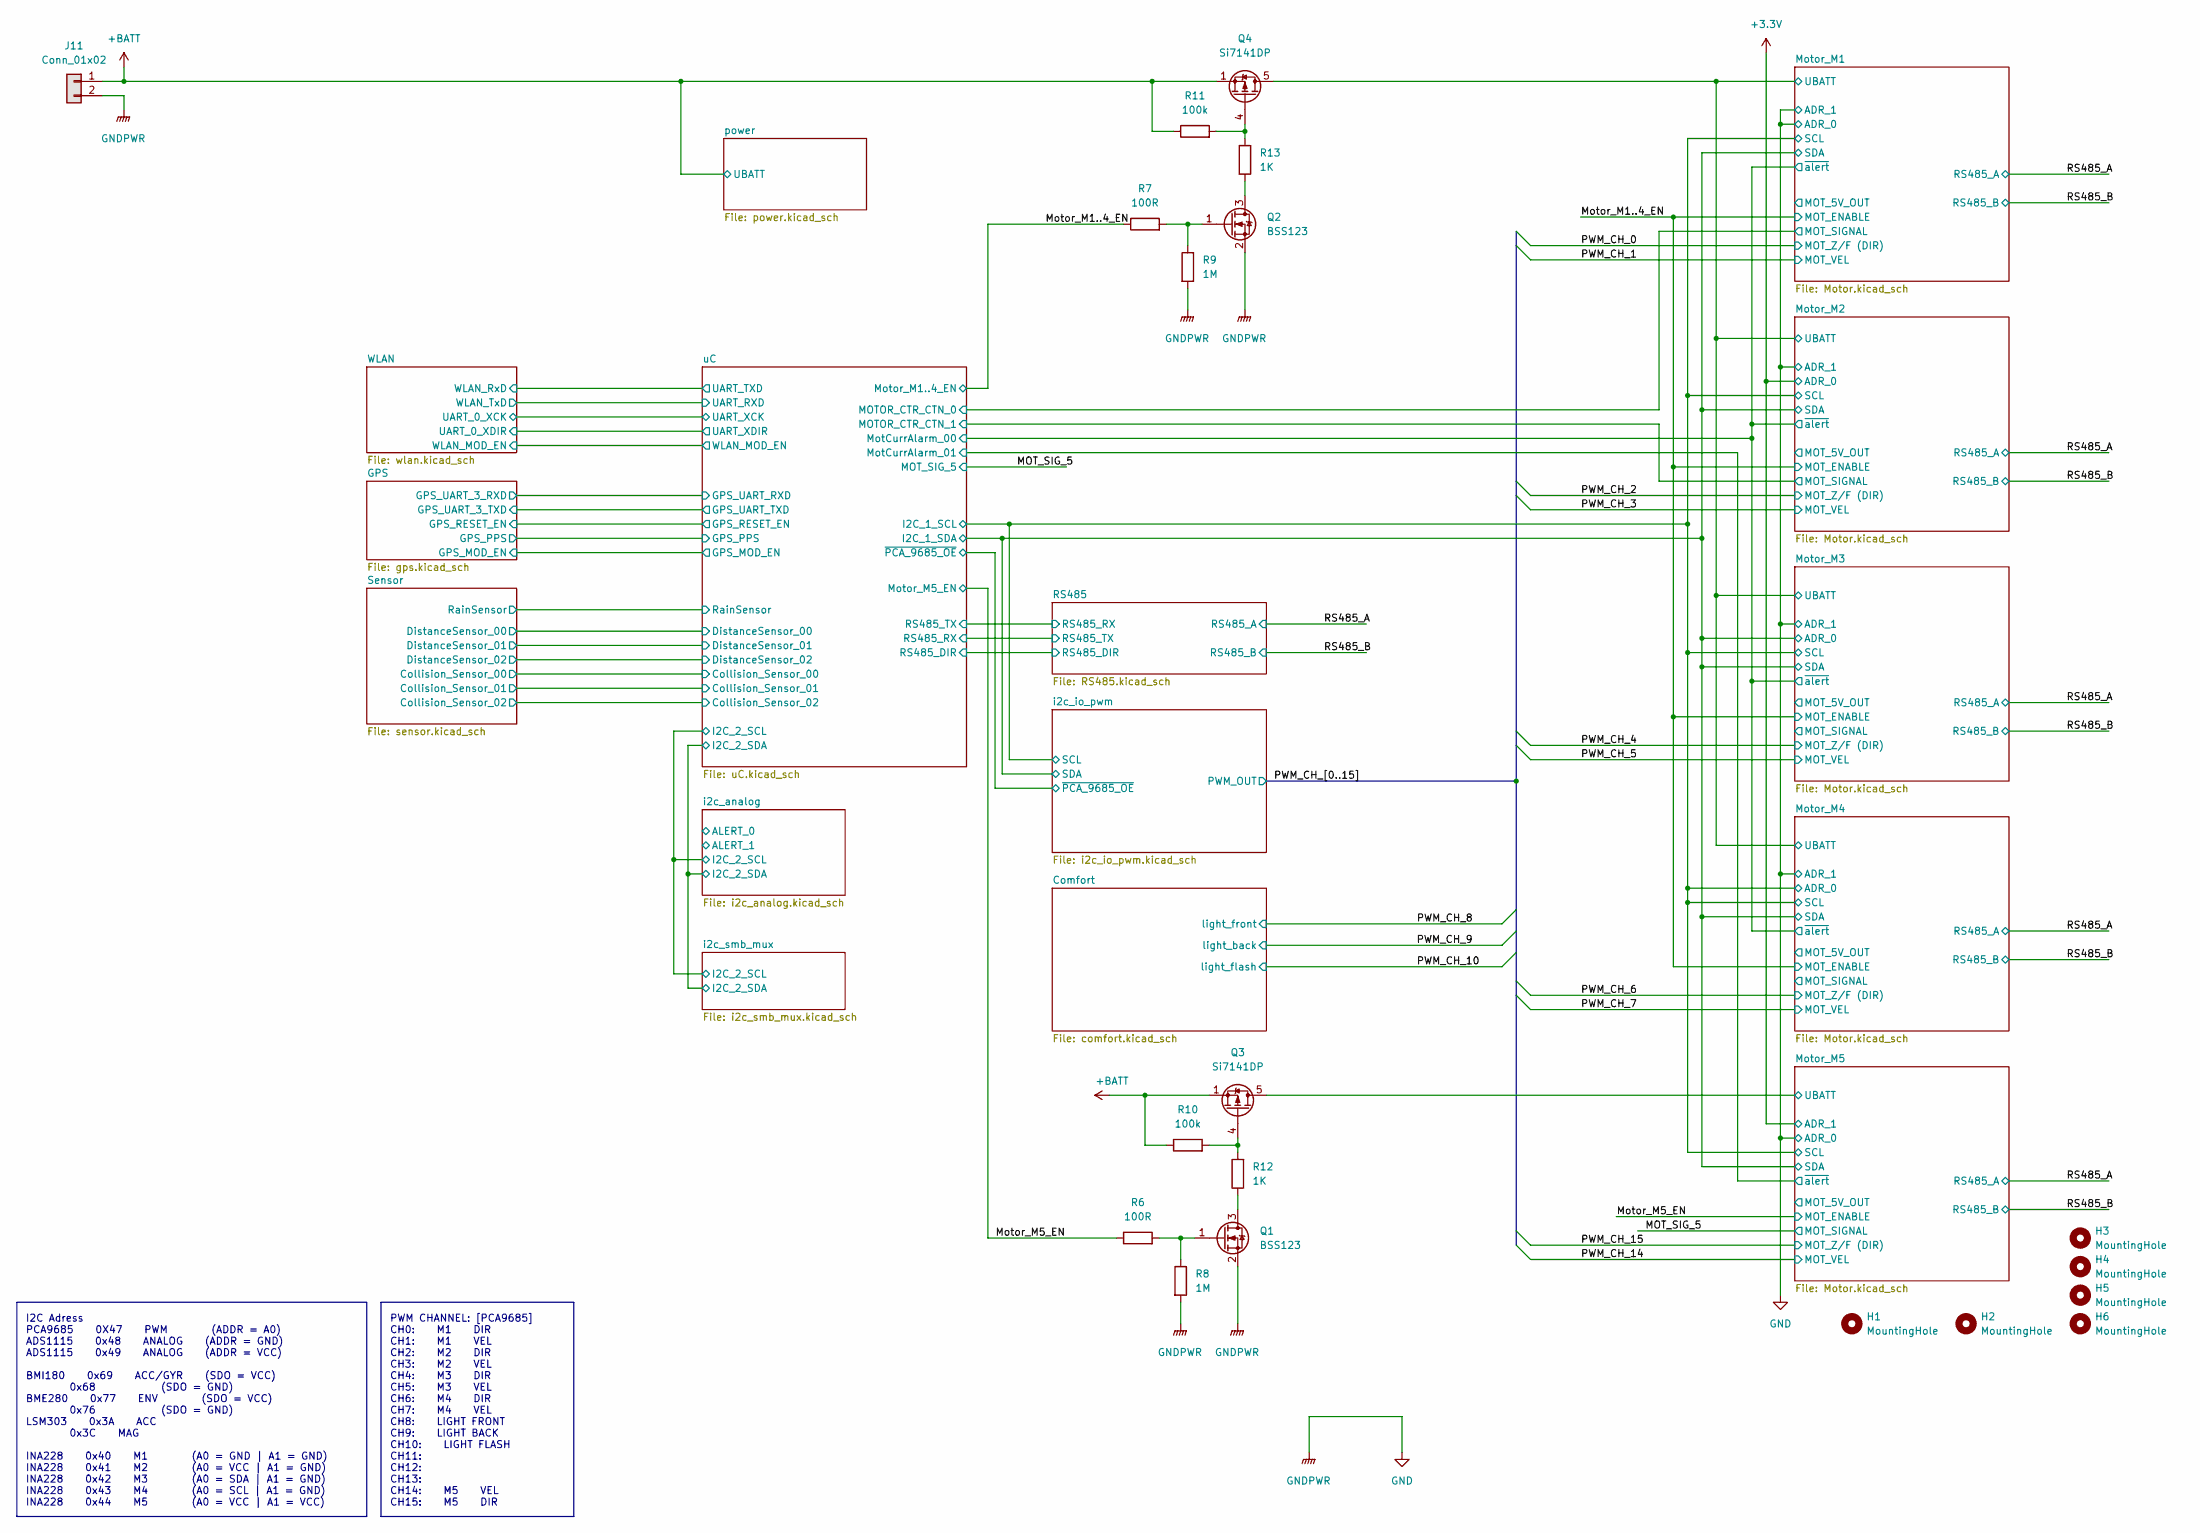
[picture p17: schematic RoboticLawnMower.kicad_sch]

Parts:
H1, H2, H3, H4, H5, H6: MountingHole; MountingHole_3.2mm_M3
J11: Conn_01x02; PhoenixContact_MCV_1,5_2-GF-3.81_1x02_P3.81mm_Vertical_Thre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
Q1, Q2: BSS123; SOT-23
Q3, Q4: Si7141DP; PowerPAK_SO-8_Single
R6, R7: 100R; R_0603_1608Metric
R8, R9: 1M; R_0603_1608Metric
R10, R11: 100k; R_0603_1608Metric
R12, R13: 1K; R_0603_1608Metric

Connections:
+BATT: J11.1, Q3.1 (S), Q3.2 (S), Q3.3 (S), Q4.1 (S), Q4.2 (S), Q4.3 (S), R10.1, R11.1; also elsewhere on the board
/Motor_M1..4_EN: R7.1; also elsewhere on the board
/Motor_M1/UBATT: Q4.5 (D); also elsewhere on the board
/Motor_M5/UBATT: Q3.5 (D); also elsewhere on the board
/Motor_M5_EN: R6.1; also elsewhere on the board
GND: J11.2, Q1.2 (S), Q2.2 (S), R8.2, R9.2; also elsewhere on the board
unnamed: Q1.3 (D), R12.1
unnamed: Q1.1 (G), R6.2, R8.1
unnamed: Q2.3 (D), R13.1
unnamed: Q2.1 (G), R7.2, R9.1
unnamed: Q3.4 (G), R10.2, R12.2
unnamed: Q4.4 (G), R11.2, R13.2

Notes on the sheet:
PWM CHANNEL: [PCA9685] CH0: M1 DIR CH1: M1 VEL CH2: M2 DIR CH3: M2 VEL CH4: M3 DIR CH5: M3 VEL CH6: M4 DIR CH7: M4 VEL CH8: LIGHT FRONT CH9: LIGHT BACK CH10: LIGHT FLASH CH11: CH12: CH13: CH14: M5 VEL CH15: M5 DIR
I2C Adress PCA9685 0X47 PWM (ADDR = A0) ADS1115 0x48 ANALOG (ADDR = GND) ADS1115 0x49 ANALOG (ADDR = VCC) BMI180 0x69 ACC/GYR (SDO = VCC) 0x68 (SDO = GND) BME280 0x77 ENV (SDO = VCC) 0x76 (SDO = GND) LSM303 0x3A ACC 0x3C MAG INA228 0x40 M1 (A0 = GND | A1 = GND) INA228 0x41 M2 (A0 = VCC | A1 = GND) 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

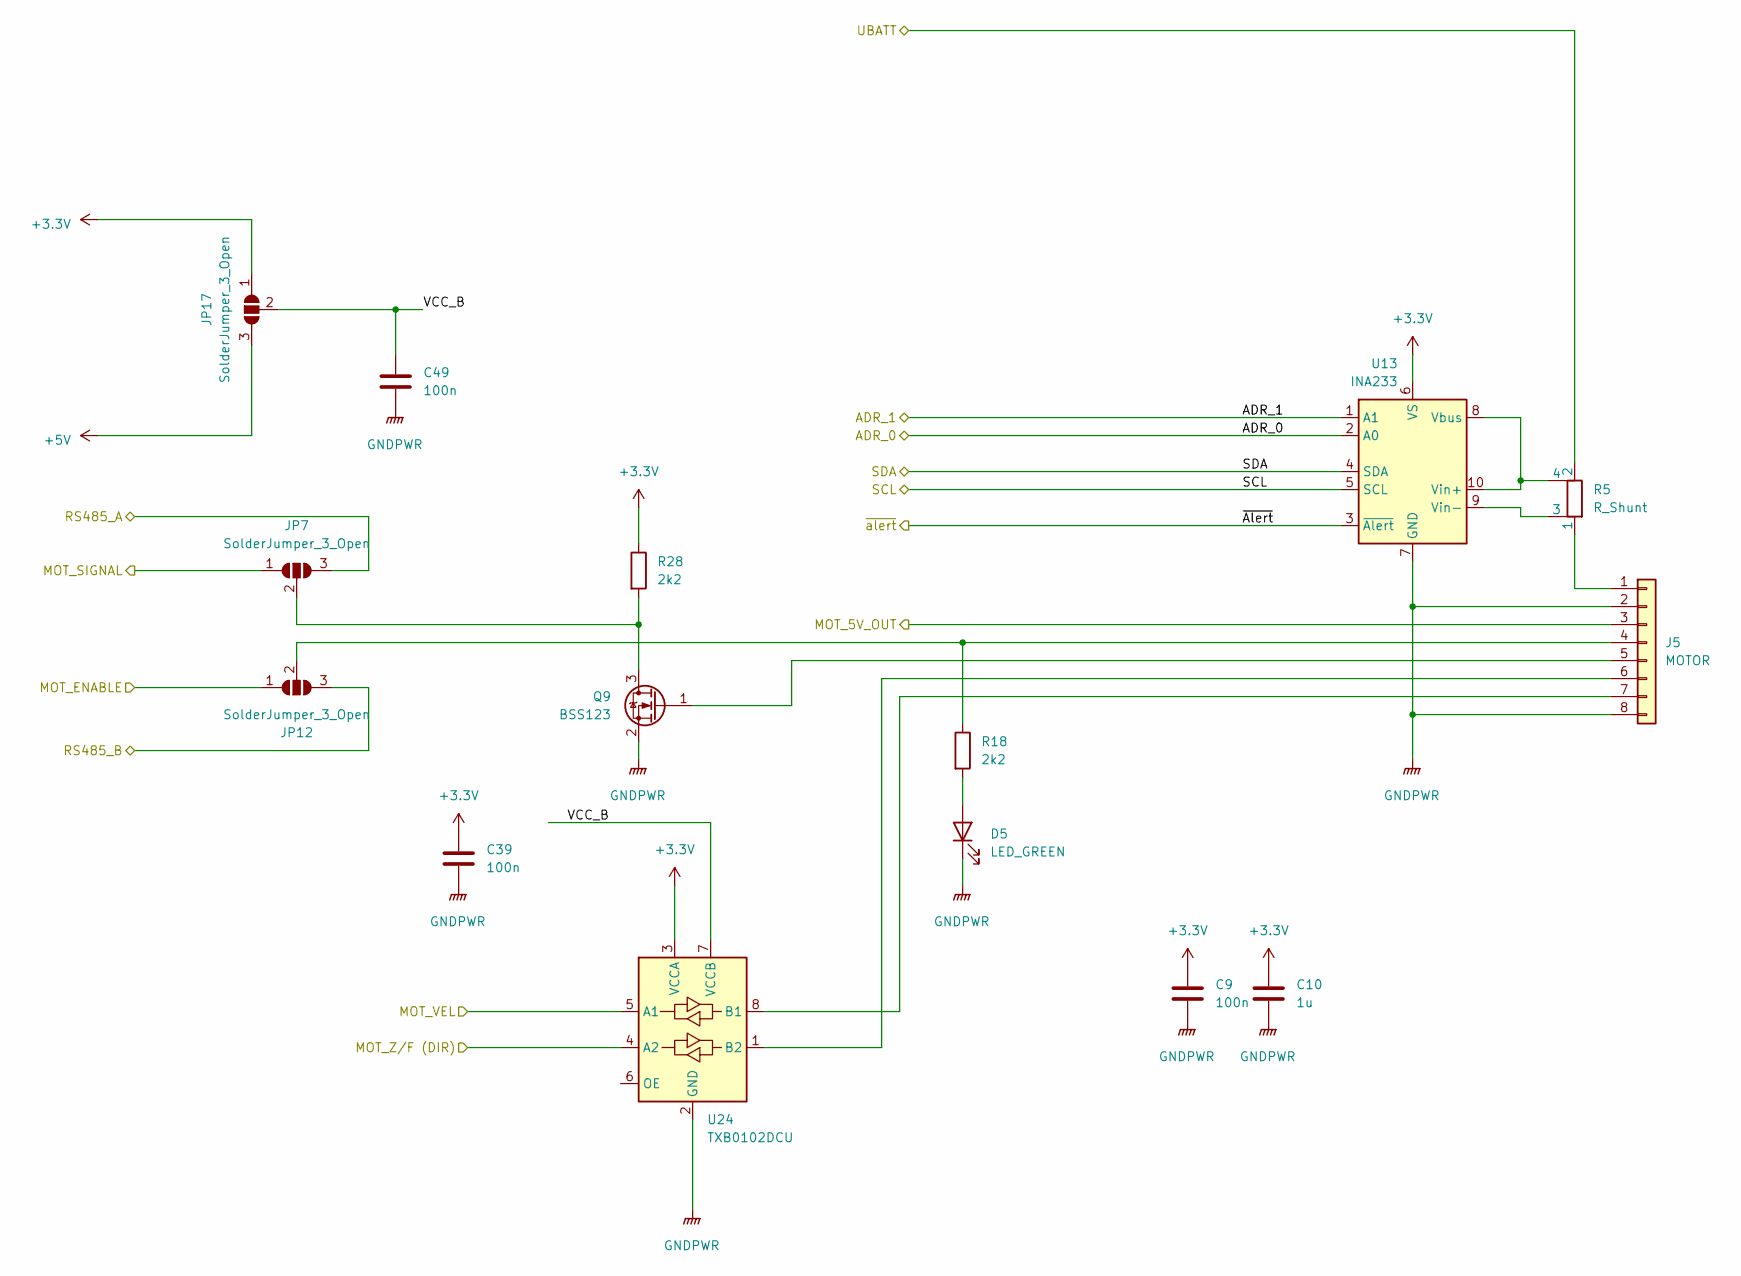
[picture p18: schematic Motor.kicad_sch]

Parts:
C9, C39, C49: 100n; C_0603_1608Metric
C10: 1u; C_0603_1608Metric
D5: LED_GREEN; LED_0603_1608Metric
J5: MOTOR; JST_XA_B08B-XASK-1_1x08_P2.50mm_Vertical
JP7, JP12, JP17: SolderJumper_3_Open; SolderJumper-3_P1.3mm_Open_RoundedPad1.0x1.5mm
Q9: BSS123; SOT-23
R5: R_Shunt; Y08500R10000F9R
R18, R28: 2k2; R_0603_1608Metric
U13: INA233; VSSOP-10_3x3mm_P0.5mm
U24: TXB0102DCU; VSSOP-8_2.4x2.1mm_P0.5mm

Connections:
+3.3V: C9.1, C10.1, C39.1, JP17.1 (A), R28.1, U13.1 (A1), U13.6 (VS), U24.3 (VCCA); also elsewhere on the board
+5V: JP17.3 (B); also elsewhere on the board
/MOT_SIG_5: JP7.1 (A); also elsewhere on the board
/Motor_M1/SCL: U13.5 (SCL); also elsewhere on the board
/Motor_M1/SDA: U13.4 (SDA); also elsewhere on the board
/Motor_M5/MOT_5V_OUT: J5.3
/Motor_M5/UBATT: R5.2; also elsewhere on the board
/Motor_M5/VCC_B: C49.1, JP17.2 (C), U24.7 (VCCB)
/Motor_M5/~Alert: U13.3 (~Alert); also elsewhere on the board
/Motor_M5_EN: JP12.1 (A); also elsewhere on the board
/PWM_CH_14: U24.5 (A1); also elsewhere on the board
/PWM_CH_15: U24.4 (A2); also elsewhere on the board
/RS485_A: JP7.3 (B); also elsewhere on the board
/RS485_B: JP12.3 (B); also elsewhere on the board
GND: C9.2, C10.2, C39.2, C49.2, D5.1 (K), J5.2, J5.8, Q9.2 (S), U13.2 (A0), U13.7 (GND), U24.2 (GND); also elsewhere on the board
unnamed: D5.2 (A), R18.2
unnamed: J5.1, R5.1
unnamed: J5.4, JP12.2 (C), R18.1
unnamed: J5.6, U24.1 (B2)
unnamed: J5.7, U24.8 (B1)
unnamed: R5.4, U13.8 (Vbus), U13.10 (Vin+)
unnamed: R5.3, U13.9 (Vin-)

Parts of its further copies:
C1, C3, C5, C7, C35, C36, C37, C38, C45, C46, C47, C48: 100n; C_0603_1608Metric
C2, C4, C6, C8: 1u; C_0603_1608Metric
D1, D2, D3, D4: LED_GREEN; LED_0603_1608Metric
J1, J2, J3, J4: MOTOR; JST_XA_B08B-XASK-1_1x08_P2.50mm_Vertical
JP3, JP4, JP5, JP6, JP8, JP9, JP10, JP11, JP13, JP14, JP15, JP16: SolderJumper_3_Open; SolderJumper-3_P1.3mm_Open_RoundedPad1.0x1.5mm
Q10, Q11, Q12, Q13: BSS123; SOT-23
R1, R2, R3, R4: R_Shunt; Y08500R10000F9R
R14, R15, R16, R17, R29, R30, R31, R32: 2k2; R_0603_1608Metric
U1, U10, U11, U12: INA233; VSSOP-10_3x3mm_P0.5mm
U20, U21, U22, U23: TXB0102DCU; VSSOP-8_2.4x2.1mm_P0.5mm

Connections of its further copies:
+3.3V: C1.1, C2.1, C3.1, C4.1, C5.1, C6.1, C7.1, C8.1, C35.1, C36.1, C37.1, C38.1, JP13.1 (A), JP14.1 (A), JP15.1 (A), JP16.1 (A), R29.1, R30.1, R31.1, R32.1, U1.6 (VS), U10.2 (A0), U10.6 (VS), U11.6 (VS), U12.6 (VS), U20.3 (VCCA), U21.3 (VCCA), U22.3 (VCCA), U23.3 (VCCA); also elsewhere on the board
+5V: JP13.3 (B), JP14.3 (B), JP15.3 (B), JP16.3 (B); also elsewhere on the board
/Motor_M1..4_EN: JP8.1 (A), JP9.1 (A), JP10.1 (A), JP11.1 (A); also elsewhere on the board
/Motor_M1/MOT_5V_OUT: J1.3
/Motor_M1/MOT_SIGNAL: JP3.1 (A); also elsewhere on the board
/Motor_M1/SCL: U1.5 (SCL), U10.5 (SCL), U11.5 (SCL), U12.2 (A0), U12.5 (SCL); also elsewhere on the board
/Motor_M1/SDA: U1.4 (SDA), U10.4 (SDA), U11.2 (A0), U11.4 (SDA), U12.4 (SDA); also elsewhere on the board
/Motor_M1/UBATT: R1.2, R2.2, R3.2, R4.2; also elsewhere on the board
/Motor_M1/VCC_B: C45.1, JP13.2 (C), U20.7 (VCCB)
/Motor_M1/~Alert: U1.3 (~Alert), U10.3 (~Alert), U11.3 (~Alert), U12.3 (~Alert); also elsewhere on the board
/Motor_M2/MOT_5V_OUT: J2.3
/Motor_M2/MOT_SIGNAL: JP4.1 (A); also elsewhere on the board
/Motor_M2/VCC_B: C46.1, JP14.2 (C), U21.7 (VCCB)
/Motor_M3/MOT_5V_OUT: J3.3
/Motor_M3/MOT_SIGNAL: JP5.1 (A)
/Motor_M3/VCC_B: C47.1, JP15.2 (C), U22.7 (VCCB)
/Motor_M4/MOT_5V_OUT: J4.3
/Motor_M4/MOT_SIGNAL: JP6.1 (A)
/Motor_M4/VCC_B: C48.1, JP16.2 (C), U23.7 (VCCB)
/PWM_CH_0: U20.4 (A2); also elsewhere on the board
/PWM_CH_1: U20.5 (A1); also elsewhere on the board
/PWM_CH_2: U21.4 (A2); also elsewhere on the board
/PWM_CH_3: U21.5 (A1); also elsewhere on the board
/PWM_CH_4: U22.4 (A2); also elsewhere on the board
/PWM_CH_5: U22.5 (A1); also elsewhere on the board
/PWM_CH_6: U23.4 (A2); also elsewhere on the board
/PWM_CH_7: U23.5 (A1); also elsewhere on the board
/RS485_A: JP3.3 (B), JP4.3 (B), JP5.3 (B), JP6.3 (B); also elsewhere on the board
/RS485_B: JP8.3 (B), JP9.3 (B), JP10.3 (B), JP11.3 (B); also elsewhere on the board
GND: C1.2, C2.2, C3.2, C4.2, C5.2, C6.2, C7.2, C8.2, C35.2, C36.2, C37.2, C38.2, C45.2, C46.2, C47.2, C48.2, D1.1 (K), D2.1 (K), D3.1 (K), D4.1 (K), J1.2, J1.8, J2.2, J2.8, J3.2, J3.8, J4.2, J4.8, Q10.2 (S), Q11.2 (S), Q12.2 (S), Q13.2 (S), U1.1 (A1), U1.2 (A0), U1.7 (GND), U10.1 (A1), U10.7 (GND), U11.1 (A1), U11.7 (GND), U12.1 (A1), U12.7 (GND), U20.2 (GND), U21.2 (GND), U22.2 (GND), U23.2 (GND); also elsewhere on the board
unnamed: D1.2 (A), R14.2
unnamed: D2.2 (A), R15.2
unnamed: D3.2 (A), R16.2
unnamed: D4.2 (A), R17.2
unnamed: J1.1, R1.1
unnamed: J1.4, JP8.2 (C), R14.1
unnamed: J1.6, U20.1 (B2)
unnamed: J1.7, U20.8 (B1)
unnamed: J2.1, R2.1
unnamed: J2.4, JP9.2 (C), R15.1
unnamed: J2.5, Q10.1 (G)
unnamed: J2.6, U21.1 (B2)
unnamed: J2.7, U21.8 (B1)
unnamed: J3.1, R3.1
unnamed: J3.4, JP10.2 (C), R16.1
unnamed: J3.5, Q11.1 (G)
unnamed: J3.6, U22.1 (B2)
unnamed: J3.7, U22.8 (B1)
unnamed: J4.1, R4.1
unnamed: J4.4, JP11.2 (C), R17.1
unnamed: J4.5, Q12.1 (G)
unnamed: J4.6, U23.1 (B2)
unnamed: J4.7, U23.8 (B1)
unnamed: JP4.2 (C), Q10.3 (D), R29.2
unnamed: JP5.2 (C), Q11.3 (D), R30.2
unnamed: JP6.2 (C), Q12.3 (D), R31.2
unnamed: R1.4, U1.8 (Vbus), U1.10 (Vin+)
unnamed: R1.3, U1.9 (Vin-)
unnamed: R2.4, U10.8 (Vbus), U10.10 (Vin+)
unnamed: R2.3, U10.9 (Vin-)
unnamed: R3.4, U11.8 (Vbus), U11.10 (Vin+)
unnamed: R3.3, U11.9 (Vin-)
unnamed: R4.4, U12.8 (Vbus), U12.10 (Vin+)
unnamed: R4.3, U12.9 (Vin-)

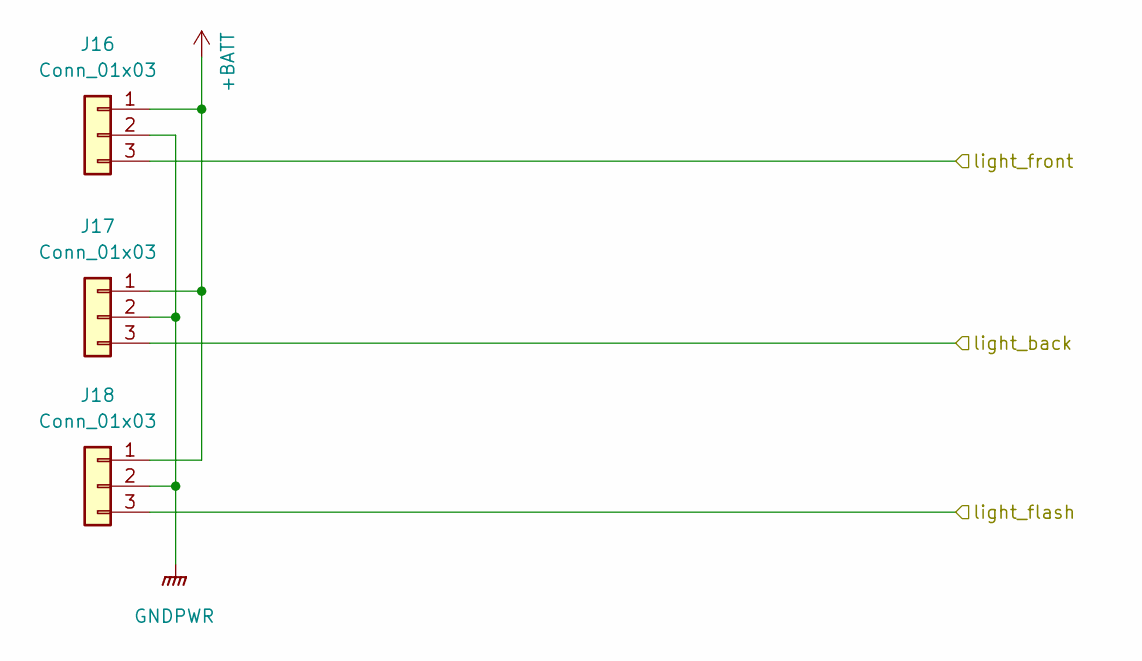
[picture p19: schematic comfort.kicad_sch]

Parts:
J16, J17, J18: Conn_01x03; JST_XA_B03B-XASK-1_1x03_P2.50mm_Vertical

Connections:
+BATT: J16.1, J17.1, J18.1; also elsewhere on the board
/PWM_CH_8: J16.3; also elsewhere on the board
/PWM_CH_9: J17.3; also elsewhere on the board
/PWM_CH_10: J18.3; also elsewhere on the board
GND: J16.2, J17.2, J18.2; also elsewhere on the board

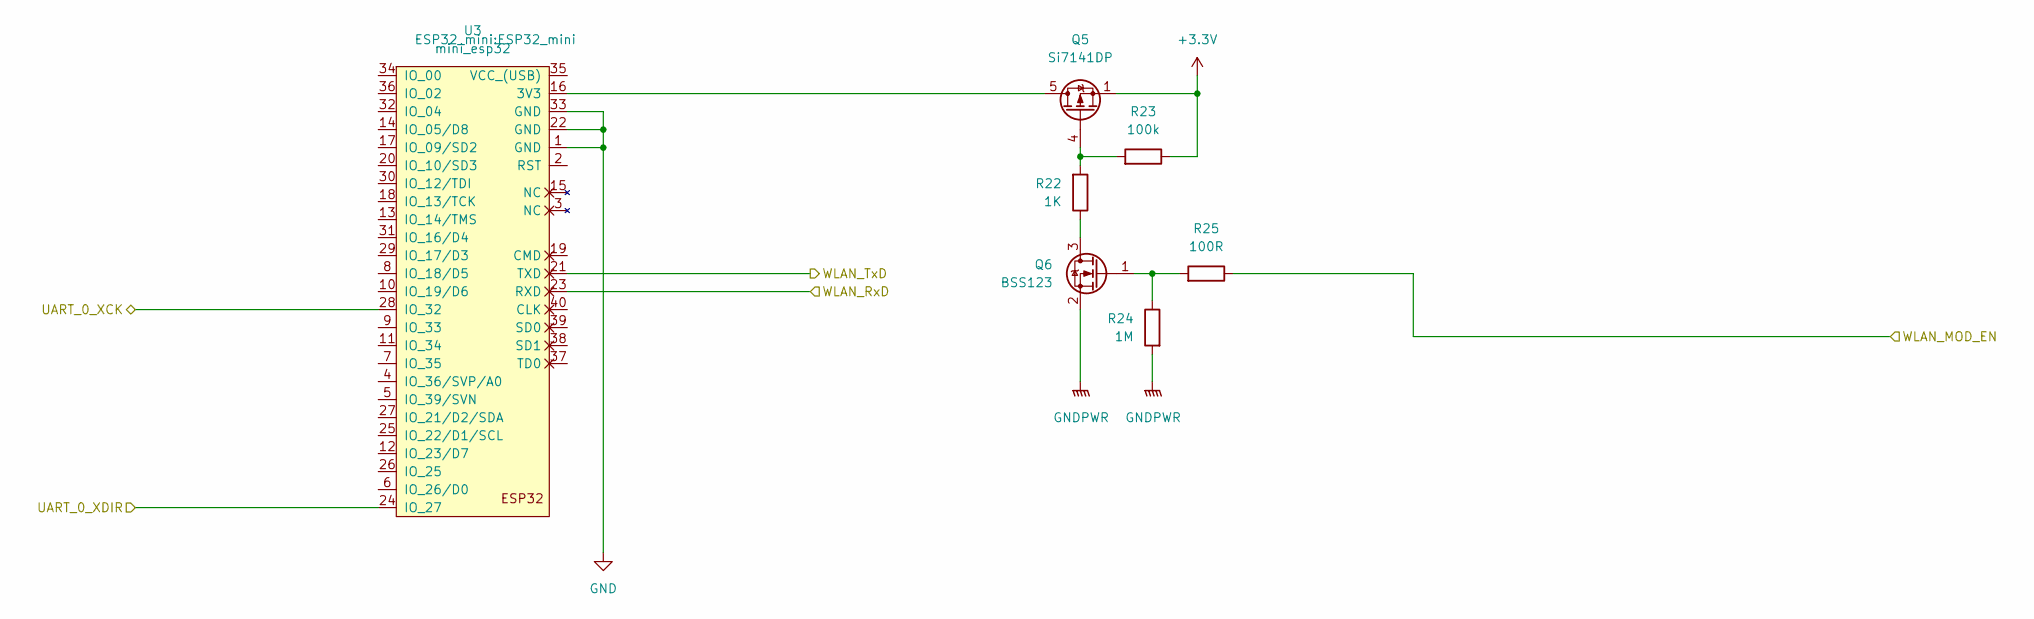
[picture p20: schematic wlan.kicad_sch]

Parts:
Q5: Si7141DP; PowerPAK_SO-8_Single
Q6: BSS123; SOT-23
R22: 1K; R_0603_1608Metric
R23: 100k; R_0603_1608Metric
R24: 1M; R_0603_1608Metric
R25: 100R; R_0603_1608Metric
U3: mini_esp32; ESP32_mini

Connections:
+3.3V: Q5.1 (S), Q5.2 (S), Q5.3 (S), R23.1; also elsewhere on the board
/WLAN/UART_0_XCK: U3.28 (IO_32); also elsewhere on the board
/WLAN/UART_0_XDIR: U3.24 (IO_27); also elsewhere on the board
/WLAN/WLAN_MOD_EN: R25.1; also elsewhere on the board
/uC/USART_2_RX: U3.21 (TXD); also elsewhere on the board
/uC/USART_2_TX: U3.23 (RXD); also elsewhere on the board
GND: Q6.2 (S), R24.2, U3.1 (GND), U3.22 (GND), U3.33 (GND); also elsewhere on the board
unnamed: Q5.5 (D), U3.16 (3V3)
unnamed: Q5.4 (G), R22.2, R23.2
unnamed: Q6.3 (D), R22.1
unnamed: Q6.1 (G), R24.1, R25.2

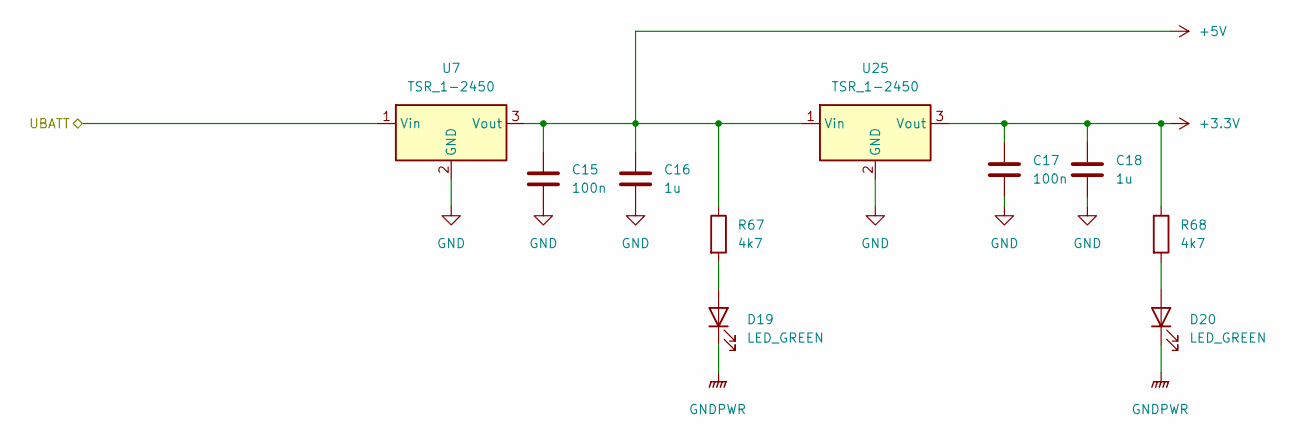
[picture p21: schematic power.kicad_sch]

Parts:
C15, C17: 100n; C_0603_1608Metric
C16, C18: 1u; C_0603_1608Metric
D19, D20: LED_GREEN; LED_0603_1608Metric
R67, R68: 4k7; R_0603_1608Metric
U7, U25: TSR_1-2450; Converter_DCDC_TRACO_TSR-1_THT

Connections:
+3.3V: C17.1, C18.1, R68.1, U25.3 (Vout); also elsewhere on the board
+5V: C15.1, C16.1, R67.1, U7.3 (Vout), U25.1 (Vin); also elsewhere on the board
+BATT: U7.1 (Vin); also elsewhere on the board
GND: C15.2, C16.2, C17.2, C18.2, D19.1 (K), D20.1 (K), U7.2 (GND), U25.2 (GND); also elsewhere on the board
unnamed: D19.2 (A), R67.2
unnamed: D20.2 (A), R68.2

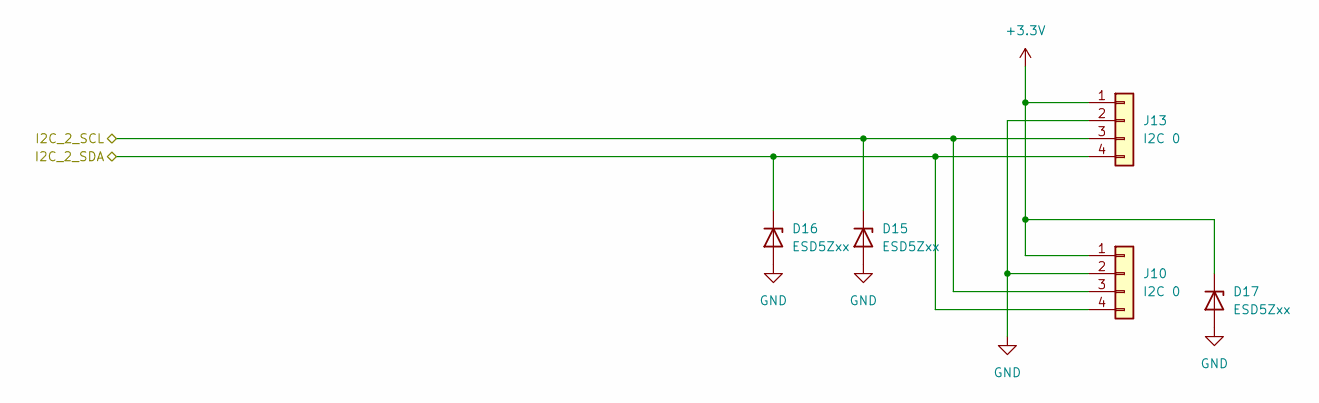
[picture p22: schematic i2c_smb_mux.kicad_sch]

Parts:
D15, D16, D17: ESD5Zxx; D_SOD-523
J10, J13: I2C 0; JST_XA_B04B-XASK-1_1x04_P2.50mm_Vertical

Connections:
+3.3V: D17.1 (K), J10.1, J13.1; also elsewhere on the board
/i2c_analog/I2C_2_SCL: D15.1 (K), J10.3, J13.3; also elsewhere on the board
/i2c_analog/I2C_2_SDA: D16.1 (K), J10.4, J13.4; also elsewhere on the board
GND: D15.2 (A), D16.2 (A), D17.2 (A), J10.2, J13.2; also elsewhere on the board

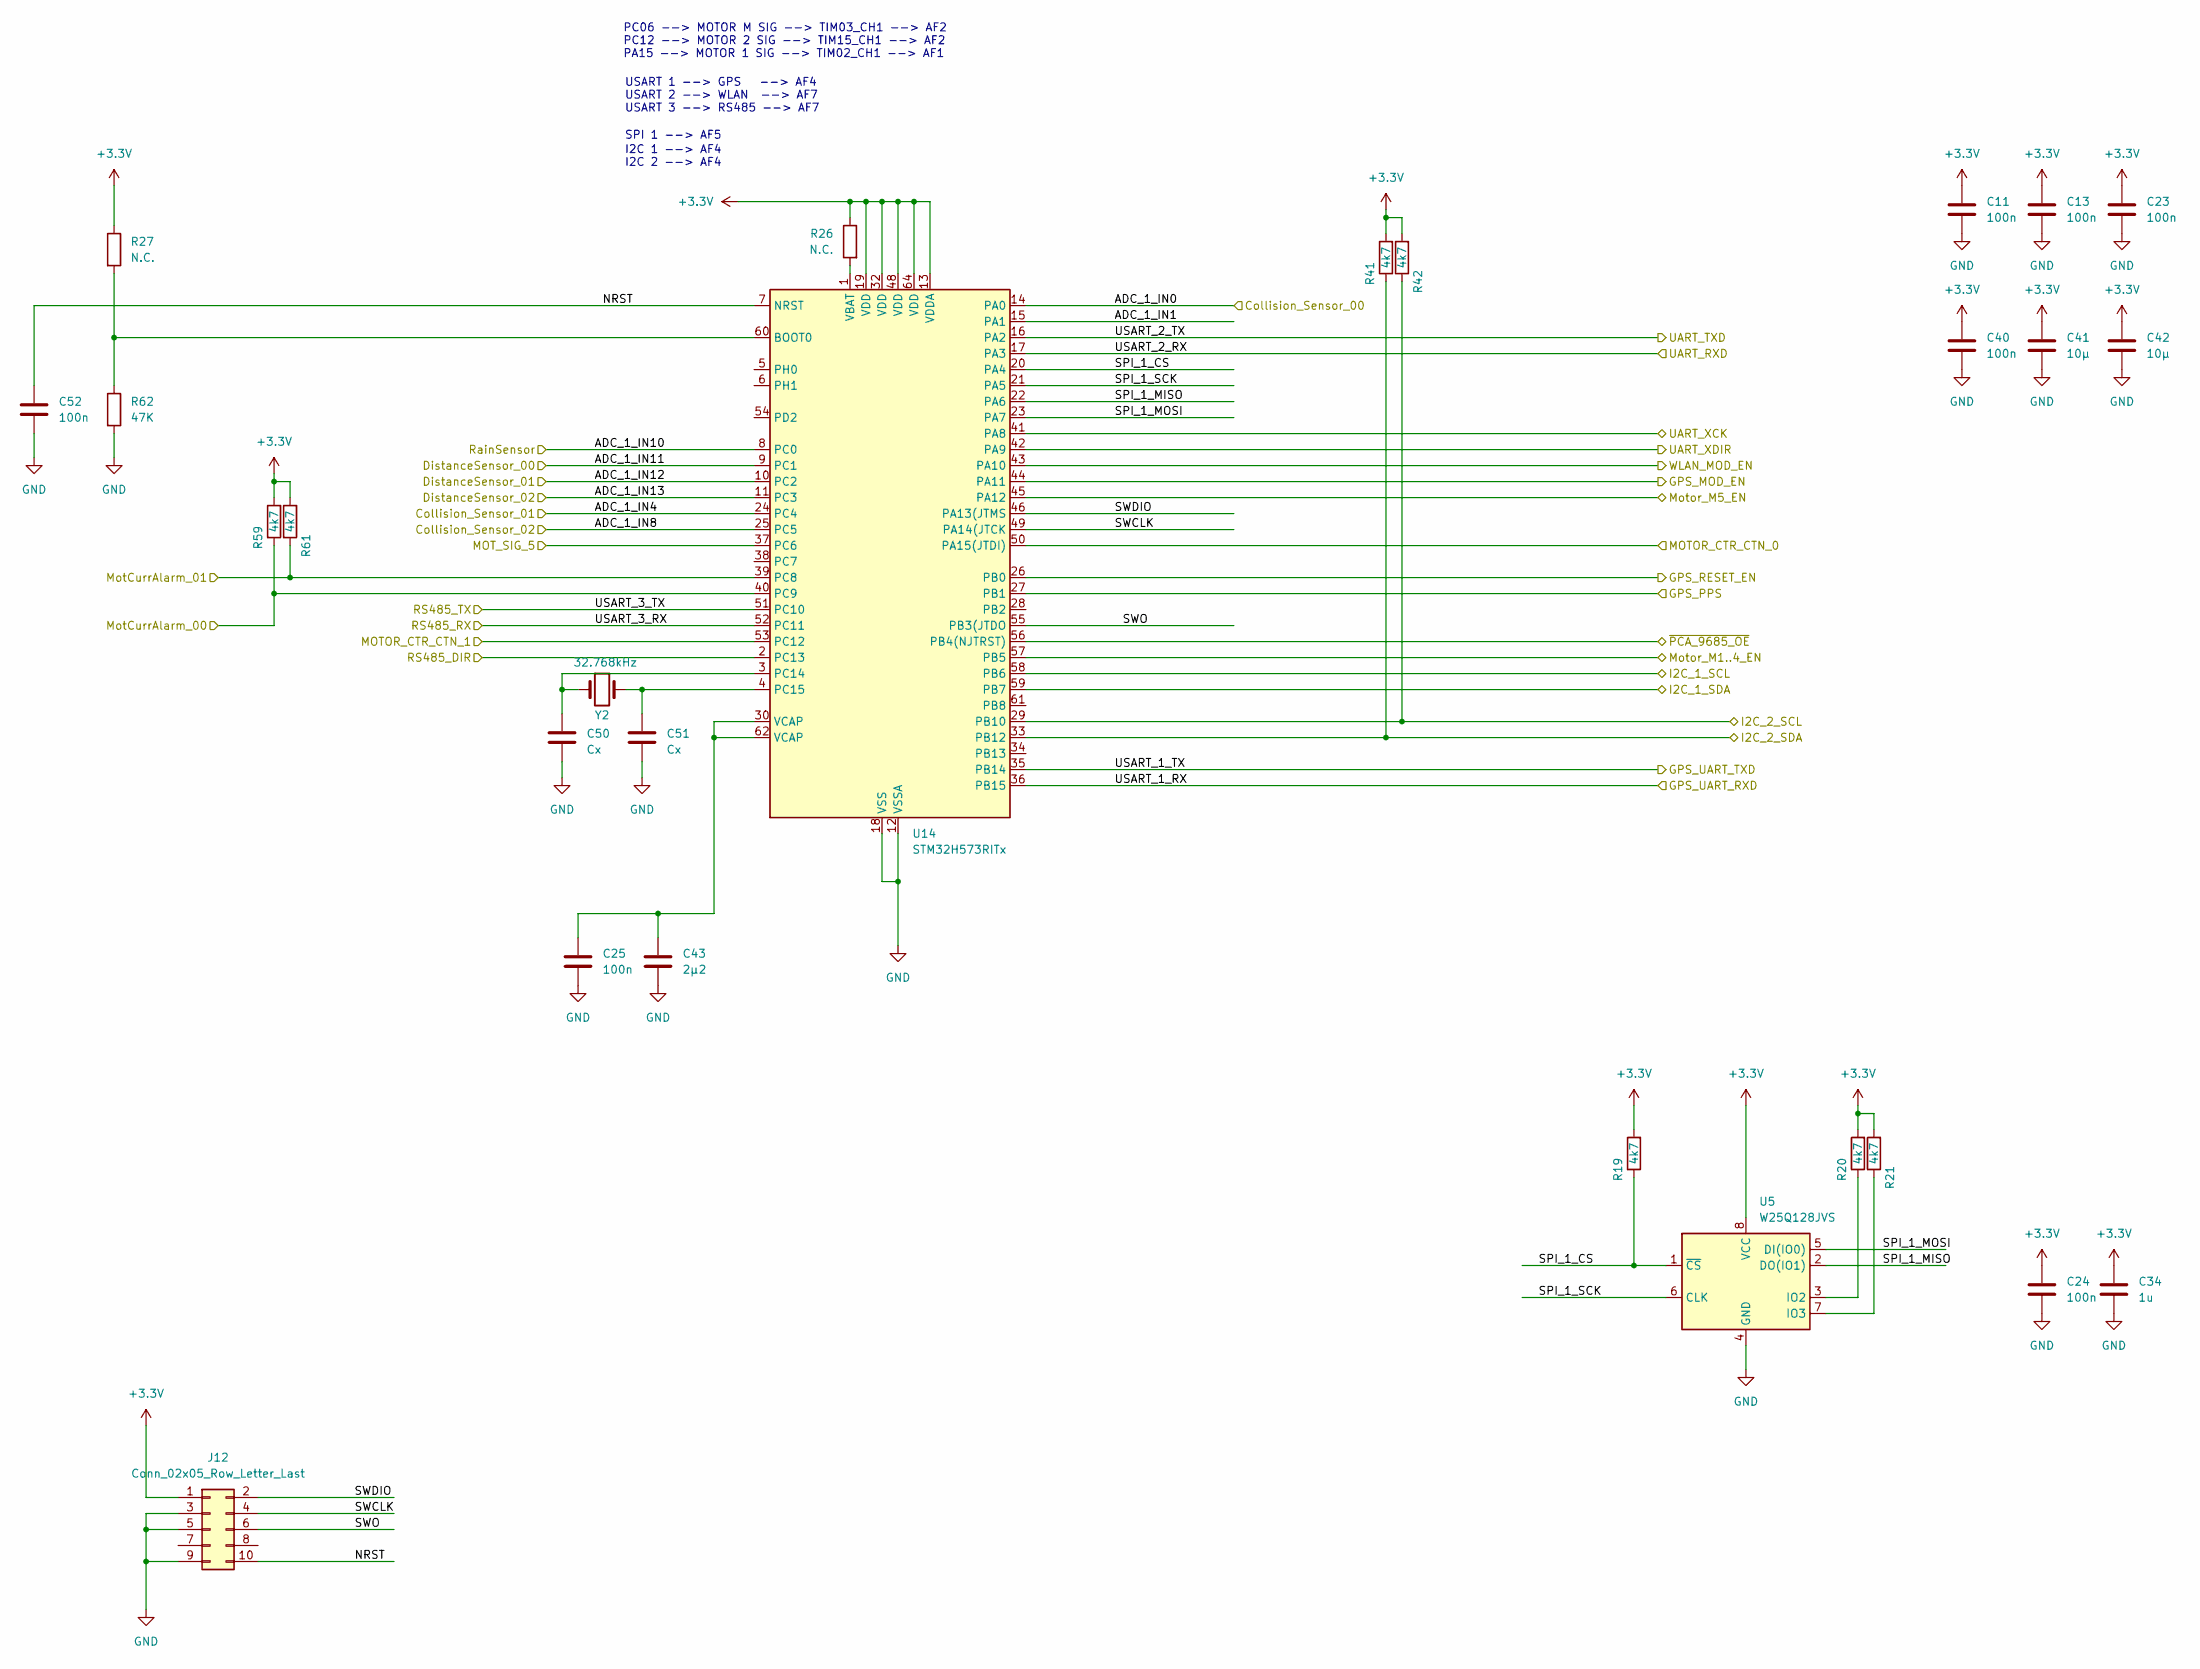
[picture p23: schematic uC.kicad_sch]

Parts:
C11, C13, C23, C24, C25, C40, C52: 100n; C_0603_1608Metric
C34: 1u; C_0603_1608Metric
C41, C42: 10µ; C_0603_1608Metric
C43: 2µ2; C_0603_1608Metric
C50, C51: Cx; C_0603_1608Metric
J12: Conn_02x05_Row_Letter_Last; PinHeader_2x05_P1.27mm_Vertical_SMD
R19, R20, R21, R41, R42, R59, R61: 4k7; R_0603_1608Metric
R26, R27: N.C.; R_0603_1608Metric
R62: 47K; R_0603_1608Metric
U5: W25Q128JVS; SOIC-8_5.23x5.23mm_P1.27mm
U14: STM32H573RITx; LQFP-64_10x10mm_P0.5mm
Y2: 32.768kHz; Crystal_SMD_3215-2Pin_3.2x1.5mm

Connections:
+3.3V: C11.1, C13.1, C23.1, C24.1, C34.1, C40.1, C41.1, C42.1, J12.1, R19.2, R20.2, R21.2, R26.1, R27.1, R41.2, R42.2, R59.2, R61.2, U5.8 (VCC), U14.13 (VDDA), U14.19 (VDD), U14.32 (VDD), U14.48 (VDD), U14.64 (VDD); also elsewhere on the board
/GPS/GPS_MOD_EN: U14.44 (PA11); also elsewhere on the board
/GPS/GPS_PPS: U14.27 (PB1); also elsewhere on the board
/GPS/GPS_RESET_EN: U14.26 (PB0); also elsewhere on the board
/MOT_SIG_5: U14.37 (PC6); also elsewhere on the board
/Motor_M1..4_EN: U14.57 (PB5); also elsewhere on the board
/Motor_M1/MOT_SIGNAL: U14.50 (PA15(JTDI)); also elsewhere on the board
/Motor_M1/SCL: U14.58 (PB6); also elsewhere on the board
/Motor_M1/SDA: U14.59 (PB7); also elsewhere on the board
/Motor_M1/~Alert: R59.1, U14.40 (PC9); also elsewhere on the board
/Motor_M2/MOT_SIGNAL: U14.53 (PC12); also elsewhere on the board
/Motor_M5/~Alert: R61.1, U14.39 (PC8); also elsewhere on the board
/Motor_M5_EN: U14.45 (PA12); also elsewhere on the board
/RS485/RS485_DIR: U14.2 (PC13); also elsewhere on the board
/Sensor/DistanceSensor_00: U14.9 (PC1); also elsewhere on the board
/Sensor/DistanceSensor_01: U14.10 (PC2); also elsewhere on the board
/Sensor/DistanceSensor_02: U14.11 (PC3); also elsewhere on the board
/Sensor/RainSensor: U14.8 (PC0); also elsewhere on the board
/WLAN/UART_0_XCK: U14.41 (PA8); also elsewhere on the board
/WLAN/UART_0_XDIR: U14.42 (PA9); also elsewhere on the board
/WLAN/WLAN_MOD_EN: U14.43 (PA10); also elsewhere on the board
/i2c_analog/I2C_2_SCL: R42.1, U14.29 (PB10); also elsewhere on the board
/i2c_analog/I2C_2_SDA: R41.1, U14.33 (PB12); also elsewhere on the board
/i2c_io_pwm/~PCA_9685_OE: U14.56 (PB4(NJTRST)); also elsewhere on the board
/uC/ADC_1_IN0: U14.14 (PA0); also elsewhere on the board
/uC/ADC_1_IN1: U14.15 (PA1)
/uC/ADC_1_IN4: U14.24 (PC4); also elsewhere on the board
/uC/ADC_1_IN8: U14.25 (PC5); also elsewhere on the board
/uC/NRST: C52.1, J12.10, U14.7 (NRST)
/uC/SPI_1_CS: R19.1, U5.1 (~CS), U14.20 (PA4)
/uC/SPI_1_MISO: U5.2 (DO(IO1)), U14.22 (PA6)
/uC/SPI_1_MOSI: U5.5 (DI(IO0)), U14.23 (PA7)
/uC/SPI_1_SCK: U5.6 (CLK), U14.21 (PA5)
/uC/SWCLK: J12.4, U14.49 (PA14(JTCK)
/uC/SWDIO: J12.2, U14.46 (PA13(JTMS)
/uC/SWO: J12.6, U14.55 (PB3(JTDO)
/uC/USART_1_RX: U14.36 (PB15); also elsewhere on the board
/uC/USART_1_TX: U14.35 (PB14); also elsewhere on the board
/uC/USART_2_RX: U14.17 (PA3); also elsewhere on the board
/uC/USART_2_TX: U14.16 (PA2); also elsewhere on the board
/uC/USART_3_RX: U14.52 (PC11); also elsewhere on the board
/uC/USART_3_TX: U14.51 (PC10); also elsewhere on the board
GND: C11.2, C13.2, C23.2, C24.2, C25.2, C34.2, C40.2, C41.2, C42.2, C43.2, C50.2, C51.2, C52.2, J12.3, J12.5, J12.9, R62.2, U5.4 (GND), U14.12 (VSSA), U14.18 (VSS), U14.31 (VSS), U14.47 (VSS), U14.63 (VSS); also elsewhere on the board
unnamed: C25.1, C43.1, U14.30 (VCAP), U14.62 (VCAP)
unnamed: R20.1, U5.3 (IO2)
unnamed: R21.1, U5.7 (IO3)
unnamed: R27.2, R62.1, U14.60 (BOOT0)
unnamed: C50.1, U14.3 (PC14), Y2.1
unnamed: C51.1, U14.4 (PC15), Y2.2
unnamed: R26.2, U14.1 (VBAT)

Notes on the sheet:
PC06 --> MOTOR M SIG --> TIM03_CH1 --> AF2 PC12 --> MOTOR 2 SIG --> TIM15_CH1 --> AF2 PA15 --> MOTOR 1 SIG --> TIM02_CH1 --> AF1
USART 1 --> GPS --> AF4 USART 2 --> WLAN --> AF7 USART 3 --> RS485 --> AF7
I2C 2 --> AF4
SPI 1 --> AF5
I2C 1 --> AF4

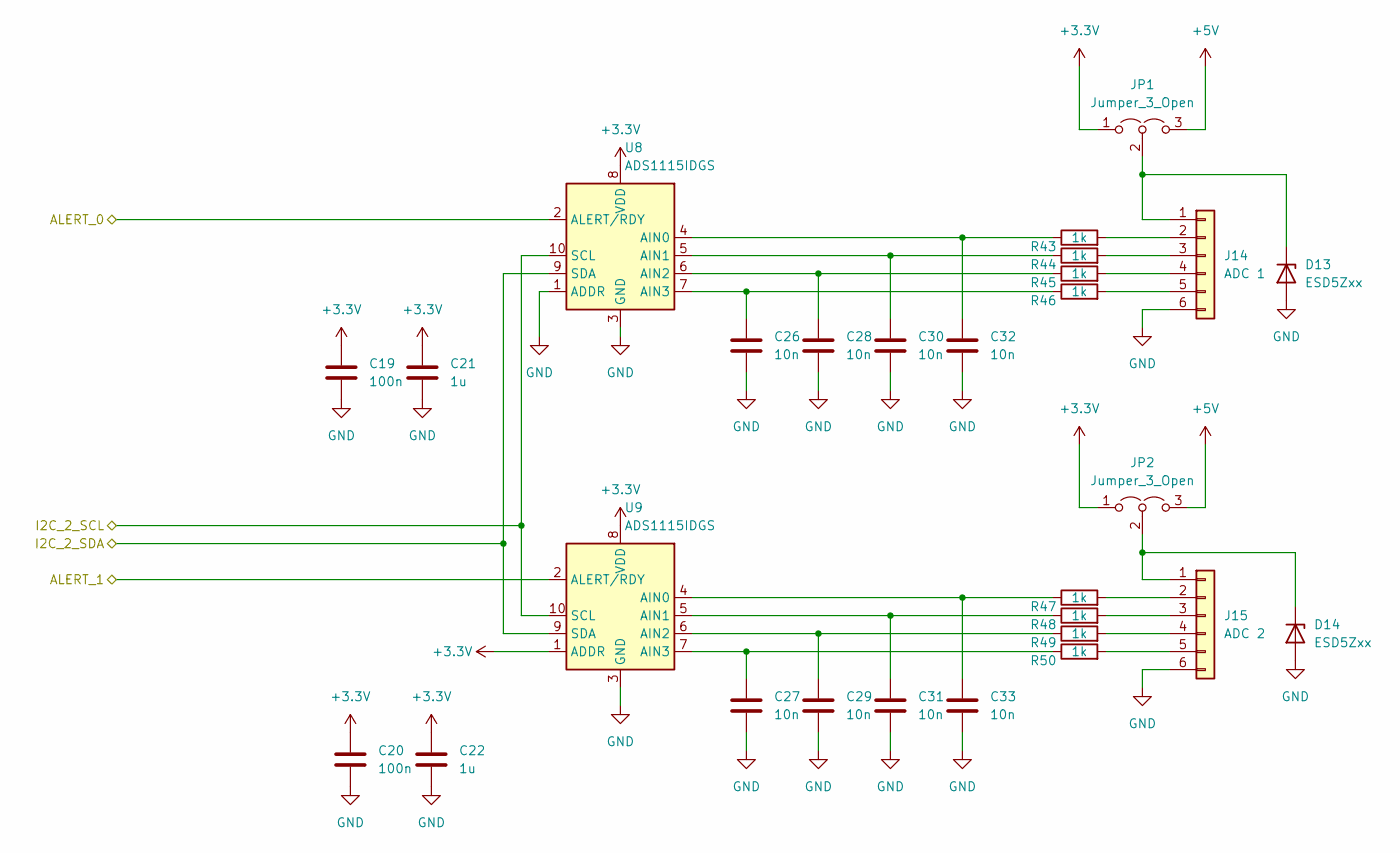
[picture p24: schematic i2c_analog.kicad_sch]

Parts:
C19, C20: 100n; C_0603_1608Metric
C21, C22: 1u; C_0603_1608Metric
C26, C27, C28, C29, C30, C31, C32, C33: 10n; C_0603_1608Metric
D13, D14: ESD5Zxx; D_SOD-523
J14: ADC 1; JST_XA_B06B-XASK-1_1x06_P2.50mm_Vertical
J15: ADC 2; JST_XA_B06B-XASK-1_1x06_P2.50mm_Vertical
JP1, JP2: Jumper_3_Open; SolderJumper-3_P1.3mm_Bridged12_RoundedPad1.0x1.5mm
R43, R44, R45, R46, R47, R48, R49, R50: 1k; R_0603_1608Metric
U8, U9: ADS1115IDGS; TSSOP-10_3x3mm_P0.5mm

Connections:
+3.3V: C19.1, C20.1, C21.1, C22.1, JP1.1 (A), JP2.1 (A), U8.8 (VDD), U9.1 (ADDR), U9.8 (VDD); also elsewhere on the board
+5V: JP1.3 (B), JP2.3 (B); also elsewhere on the board
/i2c_analog/ALERT_0: U8.2 (ALERT/RDY)
/i2c_analog/ALERT_1: U9.2 (ALERT/RDY)
/i2c_analog/I2C_2_SCL: U8.10 (SCL), U9.10 (SCL); also elsewhere on the board
/i2c_analog/I2C_2_SDA: U8.9 (SDA), U9.9 (SDA); also elsewhere on the board
GND: C19.2, C20.2, C21.2, C22.2, C26.2, C27.2, C28.2, C29.2, C30.2, C31.2, C32.2, C33.2, D13.2 (A), D14.2 (A), J14.6, J15.6, U8.1 (ADDR), U8.3 (GND), U9.3 (GND); also elsewhere on the board
unnamed: D13.1 (K), J14.1, JP1.2 (C)
unnamed: D14.1 (K), J15.1, JP2.2 (C)
unnamed: J14.2, R43.2
unnamed: J14.3, R44.2
unnamed: J14.4, R45.2
unnamed: J14.5, R46.2
unnamed: J15.2, R47.2
unnamed: J15.3, R48.2
unnamed: J15.4, R49.2
unnamed: J15.5, R50.2
unnamed: C32.1, R43.1, U8.4 (AIN0)
unnamed: C30.1, R44.1, U8.5 (AIN1)
unnamed: C28.1, R45.1, U8.6 (AIN2)
unnamed: C26.1, R46.1, U8.7 (AIN3)
unnamed: C33.1, R47.1, U9.4 (AIN0)
unnamed: C31.1, R48.1, U9.5 (AIN1)
unnamed: C29.1, R49.1, U9.6 (AIN2)
unnamed: C27.1, R50.1, U9.7 (AIN3)

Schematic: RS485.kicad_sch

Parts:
C53: 100n; C_0603_1608Metric
C54: 1u; C_0603_1608Metric
R69: 120; R_1206_3216Metric
U2: LT1785AxS8; SOIC-8_3.9x4.9mm_P1.27mm

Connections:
+3.3V: C53.1, C54.1, U2.8 (VCC); also elsewhere on the board
/RS485/RS485_DIR: U2.2 (~RE), U2.3 (DE); also elsewhere on the board
/RS485_A: R69.1, U2.6 (A); also elsewhere on the board
/RS485_B: R69.2, U2.7 (B); also elsewhere on the board
/uC/USART_3_RX: U2.1 (RO); also elsewhere on the board
/uC/USART_3_TX: U2.4 (DI); also elsewhere on the board
GND: C53.2, C54.2, U2.5 (GND); also elsewhere on the board

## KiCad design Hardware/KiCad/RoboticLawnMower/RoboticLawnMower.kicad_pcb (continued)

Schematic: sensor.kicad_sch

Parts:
D6, D7, D8, D9, D10, D11, D12: ESD5Zxx; D_SOD-523
J6: Coll 00; JST_XA_B03B-XASK-1_1x03_P2.50mm_Vertical
J7: Coll 01; JST_XA_B03B-XASK-1_1x03_P2.50mm_Vertical
J8: Coll 02; JST_XA_B03B-XASK-1_1x03_P2.50mm_Vertical
J19: RAIN; JST_XA_B03B-XASK-1_1x03_P2.50mm_Vertical
J20: Dist 00; JST_XA_B03B-XASK-1_1x03_P2.50mm_Vertical
J21: Dist 01; JST_XA_B03B-XASK-1_1x03_P2.50mm_Vertical
J22: Dist 02; JST_XA_B03B-XASK-1_1x03_P2.50mm_Vertical

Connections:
+3.3V: J6.1, J7.1, J8.1, J19.1, J20.1, J21.1, J22.1; also elsewhere on the board
/Sensor/DistanceSensor_00: D7.1 (K), J20.3; also elsewhere on the board
/Sensor/DistanceSensor_01: D8.1 (K), J21.3; also elsewhere on the board
/Sensor/DistanceSensor_02: D9.1 (K), J22.3; also elsewhere on the board
/Sensor/RainSensor: D6.1 (K), J19.3; also elsewhere on the board
/uC/ADC_1_IN0: D12.1 (K), J6.3; also elsewhere on the board
/uC/ADC_1_IN4: D11.1 (K), J7.3; also elsewhere on the board
/uC/ADC_1_IN8: D10.1 (K), J8.3; also elsewhere on the board
GND: D6.2 (A), D7.2 (A), D8.2 (A), D9.2 (A), D10.2 (A), D11.2 (A), D12.2 (A), J6.2, J7.2, J8.2, J19.2, J20.2, J21.2, J22.2; also elsewhere on the board

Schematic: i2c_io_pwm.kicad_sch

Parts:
C12: 100n; C_0603_1608Metric
C14: 1u; C_0603_1608Metric
R33: N.P.; R_0402_1005Metric
R34: 0R0; R_0402_1005Metric
U4: PCA9685PW; TSSOP-28_4.4x9.7mm_P0.65mm

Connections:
+3.3V: C12.1, C14.1, R33.1, U4.1 (A0), U4.2 (A1), U4.3 (A2), U4.28 (VDD); also elsewhere on the board
/Motor_M1/SCL: U4.26 (SCL); also elsewhere on the board
/Motor_M1/SDA: U4.27 (SDA); also elsewhere on the board
/PWM_CH_0: U4.6 (LED0); also elsewhere on the board
/PWM_CH_1: U4.7 (LED1); also elsewhere on the board
/PWM_CH_2: U4.8 (LED2); also elsewhere on the board
/PWM_CH_3: U4.9 (LED3); also elsewhere on the board
/PWM_CH_4: U4.10 (LED4); also elsewhere on the board
/PWM_CH_5: U4.11 (LED5); also elsewhere on the board
/PWM_CH_6: U4.12 (LED6); also elsewhere on the board
/PWM_CH_7: U4.13 (LED7); also elsewhere on the board
/PWM_CH_8: U4.15 (LED8); also elsewhere on the board
/PWM_CH_9: U4.16 (LED9); also elsewhere on the board
/PWM_CH_10: U4.17 (LED10); also elsewhere on the board
/PWM_CH_11: U4.18 (LED11)
/PWM_CH_12: U4.19 (LED12)
/PWM_CH_13: U4.20 (LED13)
/PWM_CH_14: U4.21 (LED14); also elsewhere on the board
/PWM_CH_15: U4.22 (LED15); also elsewhere on the board
/i2c_io_pwm/~PCA_9685_OE: U4.23 (~OE); also elsewhere on the board
GND: C12.2, C14.2, R34.2, U4.5 (A4), U4.14 (VSS), U4.24 (A5), U4.25 (EXTCLK); also elsewhere on the board
unnamed: R33.2, R34.1, U4.4 (A3)

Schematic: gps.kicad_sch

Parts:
D18: ESD5Zxx; D_SOD-523
J9: GPS; JST_XA_B07B-XASK-1_1x07_P2.50mm_Vertical
Q7: Si7141DP; PowerPAK_SO-8_Single
Q8: BSS123; SOT-23
R63: 1K; R_0603_1608Metric
R64: 100k; R_0603_1608Metric
R65: 1M; R_0603_1608Metric
R66: 100R; R_0603_1608Metric
U6: SRV05-4; SOT-23-6

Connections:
+3.3V: Q7.1 (S), Q7.2 (S), Q7.3 (S), R64.1; also elsewhere on the board
/GPS/GPS_MOD_EN: D18.1 (K), J9.7, R66.1; also elsewhere on the board
/GPS/GPS_PPS: J9.6, U6.1 (IO1); also elsewhere on the board
/GPS/GPS_RESET_EN: J9.5, U6.3 (IO2); also elsewhere on the board
/uC/USART_1_RX: J9.4, U6.4 (IO3); also elsewhere on the board
/uC/USART_1_TX: J9.3, U6.6 (IO4); also elsewhere on the board
GND: D18.2 (A), J9.2, Q8.2 (S), R65.2, U6.2 (VN); also elsewhere on the board
unnamed: J9.1, Q7.5 (D), U6.5 (VP)
unnamed: Q7.4 (G), R63.2, R64.2
unnamed: Q8.3 (D), R63.1
unnamed: Q8.1 (G), R65.1, R66.2

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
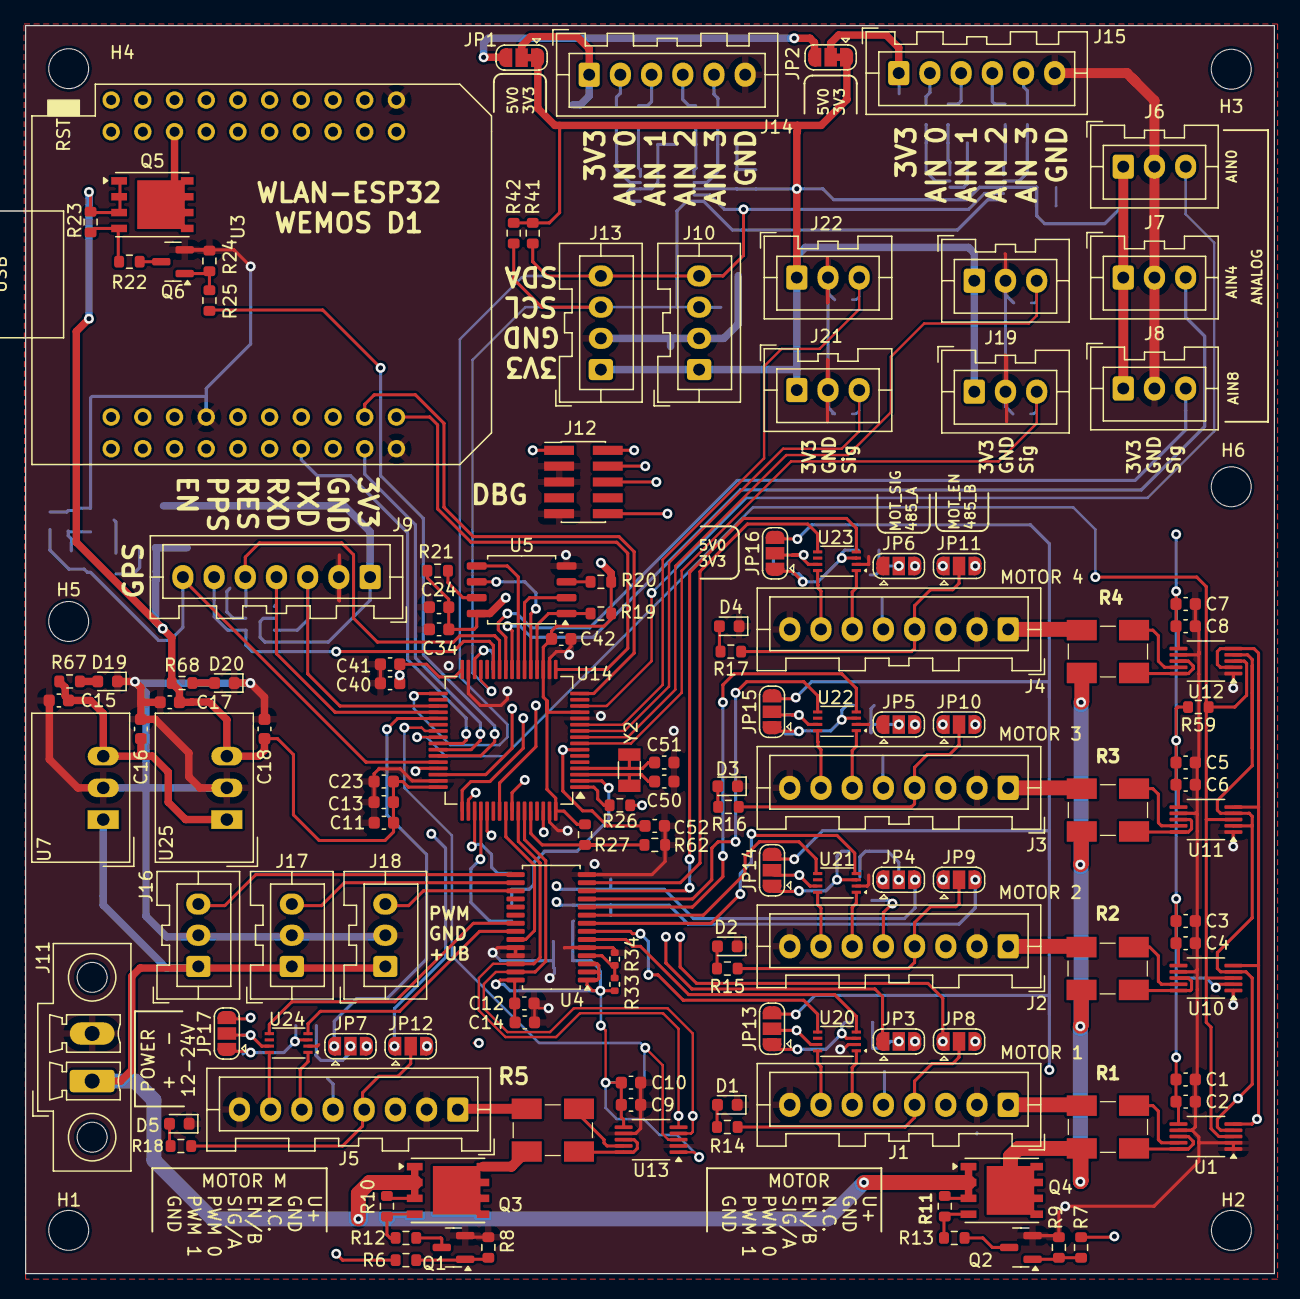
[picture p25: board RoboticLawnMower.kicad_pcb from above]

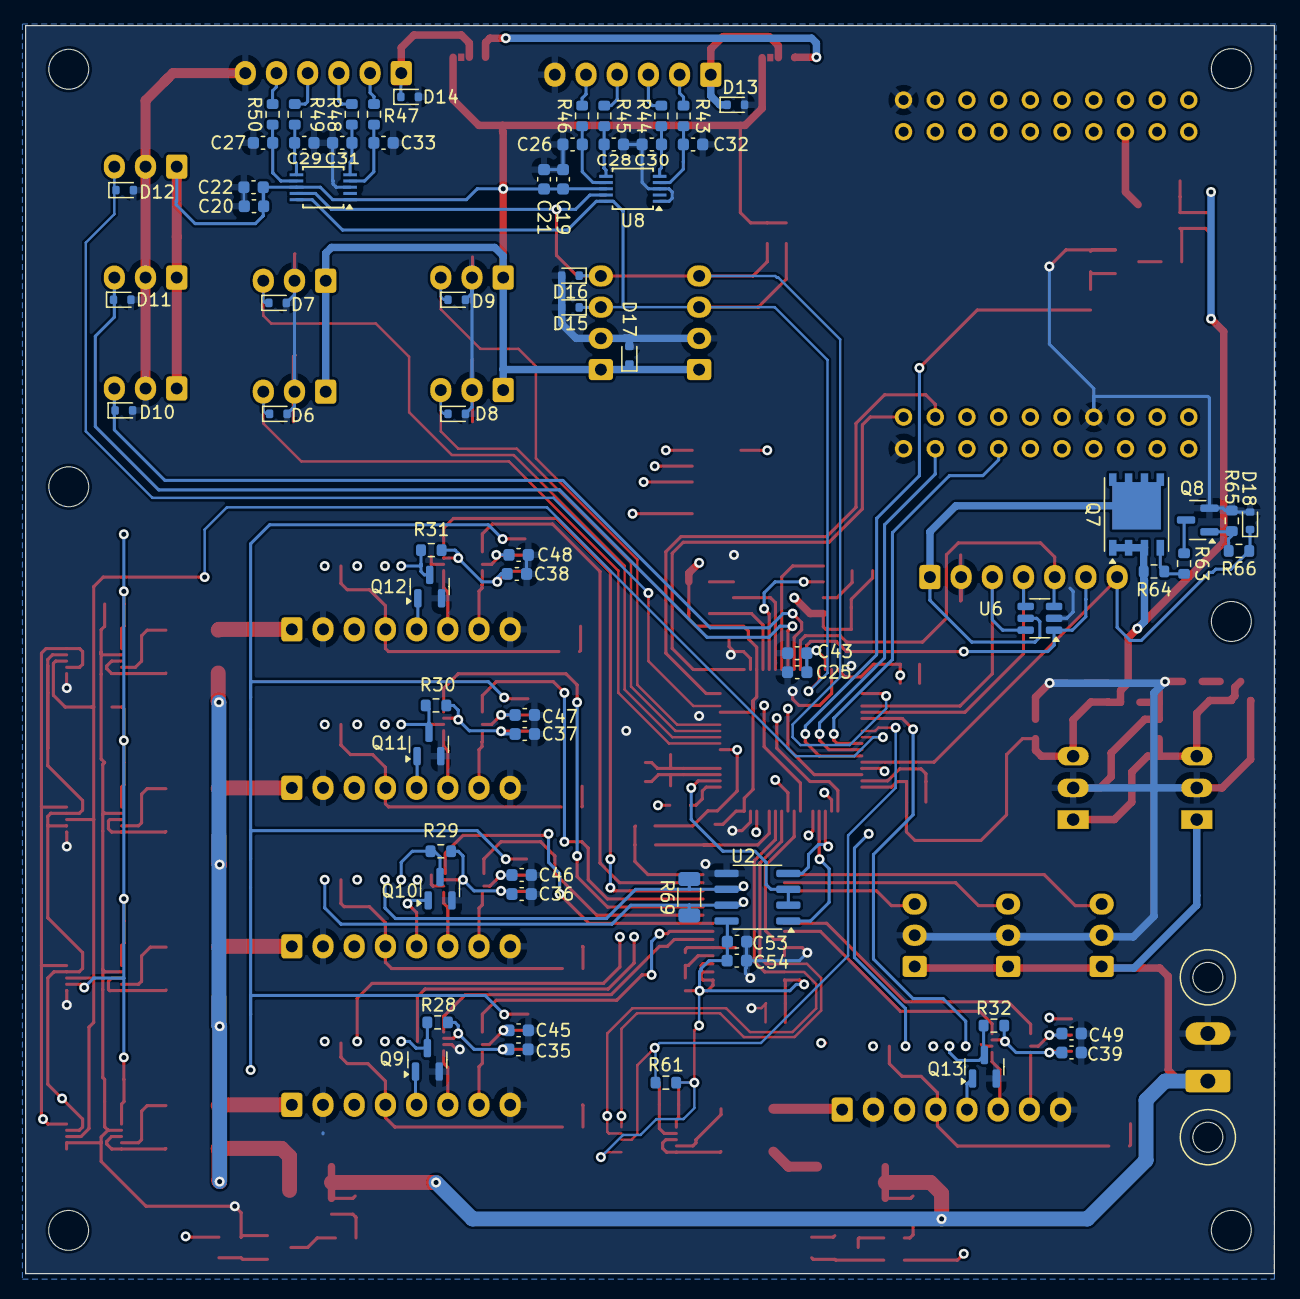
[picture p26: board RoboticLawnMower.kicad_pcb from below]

Board: 4 copper layers, 100.1 x 100.0 mm, 206 parts (69 on the bottom side), 153 nets.

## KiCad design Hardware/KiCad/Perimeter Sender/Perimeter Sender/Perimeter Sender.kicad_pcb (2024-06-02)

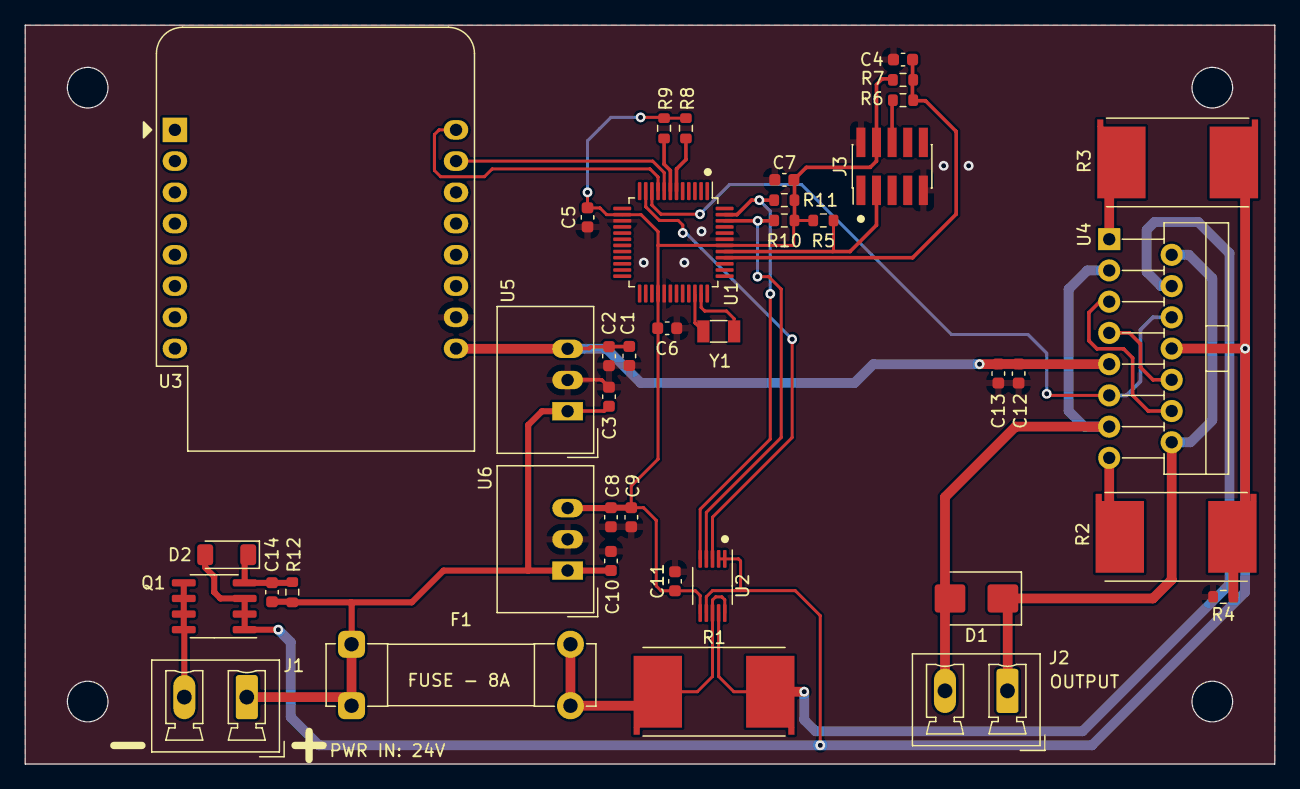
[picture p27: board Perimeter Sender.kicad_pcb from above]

Board: 2 copper layers, 101.6 x 60.1 mm, 40 parts (0 on the bottom side), 28 nets.

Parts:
C1, C3, C8, C10: 100nF; C_0603_1608Metric
C2, C9: 4u7; C_0603_1608Metric
C4: 5p6; C_0603_1608Metric
C5, C6, C7, C11, C12: 100n; C_0603_1608Metric
C13: 1uF; C_0603_1608Metric
C14: 1nF; C_0603_1608Metric
D1: SMBJ30; D_SMB
D2: BZV55B10; D_MiniMELF
F1: 10A; Fuseholder_Clip-5x20mm_Bel_FC-203-22_Lateral_P17.80x5.00mm_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
J1, J2: Conn_01x02; PhoenixContact_MCV_1,5_2-G-5.08_1x02_P5.08mm_Vertical
J3: Conn_02x05_Row_Letter_Last; PinHeader_2x05_P1.27mm_Vertical_SMD
Q1: Si4162DY; SOIC-8_3.9x4.9mm_P1.27mm
R1, R2, R3: 0.01; R_Shunt_Vishay_WSR2_WSR3_KelvinConnection
R4: 0R0; R_0603_1608Metric
R5, R7: 47K; R_0603_1608Metric
R6: 33R; R_0603_1608Metric
R8, R9, R10, R11: 4k7; R_0603_1608Metric
R12: 10K; R_0603_1608Metric
U1: AVR128DA48x-xPT; TQFP-48_7x7mm_P0.5mm
U2: INA233; VSSOP-10_3x3mm_P0.5mm
U3: WeMos_D1_mini; WEMOS_D1_mini_light
U4: L298N; TO-220-15_P2.54x2.54mm_StaggerOdd_Lead4.58mm_Vertical
U5: TSR_1-2450; Converter_DCDC_TRACO_TSR-1_THT
U6: TSR_1-2433; Converter_DCDC_TRACO_TSR-1_THT
Y1: 32.768kHz; Crystal_SMD_3215-2Pin_3.2x1.5mm

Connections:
+3.3V: C5.1, C6.1, C7.1, C8.1, C9.1, C11.1, J3.4, R5.1, R7.1, R8.2, R9.2, R10.2, R11.2, U1.14 (VDD), U1.28 (AVDD), U1.42 (VDD), U2.6 (VS), U6.3 (Vout)
+5V: C1.1, C2.1, C12.1, C13.1, U3.9 (5V), U4.9 (Vss), U5.3 (Vout)
/POWER/POWER_IN_NEG: J1.2, Q1.5 (D), Q1.6 (D), Q1.7 (D), Q1.8 (D)
/POWER/POWER_IN_POS: C3.1, C10.1, C14.1, F1.1, J1.1, R12.1, U5.1 (Vin), U6.1 (Vin)
/POWER/POWER_NEG: D2.2 (A), Q1.1 (S), Q1.2 (S), Q1.3 (S), R2.1, R3.1, R4.1, U2.1 (A1), U2.2 (A0), U2.7 (GND), U4.8 (GND)
/POWER_OUTPUT/EN: U1.10 (PC0), U4.6 (EnA), U4.11 (EnB)
/POWER_OUTPUT/IN_1: U4.5 (IN1), U4.12 (IN4)
/POWER_OUTPUT/IN_2: U4.7 (IN2), U4.10 (IN3)
/POWER_OUTPUT/LOOP_A: D1.1 (K), J2.1, U4.2 (OUT1), U4.14 (OUT4)
/POWER_OUTPUT/LOOP_B: D1.2 (A), J2.2, U4.3 (OUT2), U4.13 (OUT3)
/POWER_OUTPUT/SCL: R11.1, U1.47 (PA3), U2.5 (SCL)
/POWER_OUTPUT/SDA: R10.1, U1.46 (PA2), U2.4 (SDA)
/POWER_OUTPUT//ALERT: U1.11 (PC1), U2.3 (~Alert)
/uC/AVR_UPDI: J3.3, R5.2, U1.41 (UPDI)
/uC/I2C_1_SCL: R9.1, U1.7 (PB3)
/uC/I2C_1_SDA: R8.1, U1.6 (PB2)
/uC/UART_3_RXD: U1.9 (PB5), U3.16 (TX)
/uC/UART_3_TXD: U1.8 (PB4), U3.15 (RX)
/uC/~AVR_RERSET: C4.1, R6.2, R7.2, U1.40 (~RESET/PF6)
GND: C1.2, C2.2, C3.2, C4.2, C5.2, C6.2, C7.2, C8.2, C9.2, C10.2, C11.2, C12.2, C13.2, J3.2, J3.9, R4.2, U1.15 (GND), U1.29 (GND), U1.43 (GND), U3.10 (GND), U5.2 (GND), U6.2 (GND)
unnamed: C14.2, D2.1 (K), Q1.4 (G), R12.2
unnamed: J3.6, R6.1
unnamed: U1.34 (XTAL32K1/PF0), Y1.2
unnamed: U1.35 (XTAL32K2/PF1), Y1.1
unnamed: F1.2, R1.1, U2.8 (Vbus), U2.10 (Vin+)
unnamed: R1.2, U2.9 (Vin-), U4.4 (Vs)
unnamed: R3.2, U4.1 (SENSE_A)
unnamed: R2.2, U4.15 (SENSE_B)

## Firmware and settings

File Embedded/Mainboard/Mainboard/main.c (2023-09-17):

/*
 * AVR128DB48_C_Example.c
 *
 * Created: 12/10/2020 1:11:14 PM
 * Author : JThiessen
 */ 

// light version:	-Wl,-u,vfprintf -lprintf_min		(~1.3KB)
// full version:	-Wl,-u,vfprintf -lprintf_flt -lm	(~2.0KB) (with floating point)
//#define F_CPU                           (4000000UL)         /* using default clock 4MHz*/

#define USE_FREE_RTOS

// ********************************************************************************
// Includes
// ********************************************************************************
#include <avr/io.h>
#include <avr/interrupt.h>
#include <stdint.h>
#include <util/delay.h>
#include <stdio.h>
#include <string.h>
#include <avr/cpufunc.h>
#include <string.h>

#include "hal/i2c.h"
#include "hal/spi_basic.h"
#include "hal/port.h"
#include "hal/uart.h"
#include "hal/adc.h"

#include "commonDriver.h"

#ifdef USE_FREE_RTOS

	#include "OS/freeRTOS/include/FreeRTOS.h"
	#include "OS/freeRTOS/include/task.h"
	#include "OS/freeRTOS/include/stream_buffer.h"
	#include "OS/freeRTOS/include/message_buffer.h"
	
	#include "commonOS.h"
	#include "taskCommuncation.h"
	#include "taskEnvSensor.h"
	#include "taskGPS.h"
	#include "taskMotion.h"
	
	#include "commonDataMgmt.h"
#endif

// ********************************************************************************
// Macros and Defines
// ********************************************************************************



#define MAXPIX 8
#define COLORLENGTH MAXPIX/2
#define FADE 256/COLORLENGTH

#ifdef USE_FREE_RTOS
	#define COMMUNICATION_TASK_PRIORITY		1
	#define GPS_TASK_PRIORITY				3
	#define ENV_SESNOR_TASK_PRIORITY		4
	#define MOTION_TASK_PRIORITY			2
	
	void vControlTask(void* pvParameters);
	void vUartTask(void* pvParameters);
#endif
// ********************************************************************************
// Function Prototypes
// ********************************************************************************
void PORT_init(void);

// ********************************************************************************
// Global Variables
// ********************************************************************************

void PORT_init(void)
{
	/*
	PORTB.DIR |= LED0;
	PORTB.OUT |= LED0;

	PORTB.DIR &= ~(SW0);
	PORTB.PIN2CTRL |= PORT_PULLUPEN_bm;
	
	PORTD.DIR |= DIO;
	PORTD.OUT |= DIO;
	*/
	//SENSOR_COLLISION_PORT.DIR &= ~(SENSOR_COLLISION_00);
	//SENSOR_COLLISION_PORT.DIR &= ~(SENSOR_COLLISION_01);
	//SENSOR_COLLISION_PORT.DIR &= ~(SENSOR_COLLISION_02);
	PORTD_set_pin_dir(SENSOR_COLLISION_00, PORT_DIR_IN);
	PORTD_set_pin_dir(SENSOR_COLLISION_01, PORT_DIR_IN);
	PORTD_set_pin_dir(SENSOR_COLLISION_02, PORT_DIR_IN);
	
	PORTC.DIR |= MOTOR_EN_M1;
	PORTC.OUT |= MOTOR_EN_M1;
	
	PORTC.DIR |= MOTOR_EN_M5;
	PORTC.OUT |= MOTOR_EN_M5;
	
	PORTB.DIR |= PIN_WLAN_EN;
	PORTB.OUT |= PIN_WLAN_EN;
}


int main(void)
{
	// setup our stdio stream
//	stdout = &mystdout;

	CLOCK_OSCHF_crystal_PLL_init(CLKCTRL_FREQSEL_24M_gc);

	PORT_init();
	//TCA1_init();
	
	USART0_init(PIN4_bm, PIN5_bm, 1, 115200);
	USART3_init(PIN4_bm, PIN5_bm, 1, 9600);
	
	I2C_0_init(PORTMUX_TWI0_DEFAULT_gc, I2C_SCL_FREQ);
	I2C_1_init(PORTMUX_TWI1_ALT2_gc, I2C_SCL_FREQ);	
				
	I2C_0_scan(0x01, 0x7F);
	I2C_1_scan(0x01, 0x7F);

/*		
	printf("I2C_0:												\n\r	\
			BMM150_I2C_ADDRESS_CSB_HIGH_SDO_HIGH		0x13	\n\r	\
			ADS1115_IIC_ADDRESS_0						0x48	\n\r	\
			ADS1115_IIC_ADDRESS_1						0x49	\n\r	\
			BMI160_I2C_ADDR_SEC							0x69	\n\r	\
			BME280_I2C_ADDR_SEC							0x77	\n\r	\
			I2C_1:												\n\r	\
			INA228										0x40	\n\r	\
			INA228										0x41	\n\r	\
			INA233										0x44	\n\r	\
			PCA9685_A0_A1								0x47	\n\r");
*/
	sei();

	PORTC_set_pin_level(MOTOR_EN_M1, true);
	PORTC_set_pin_level(MOTOR_EN_M5, true);
	
	static char tx_buff[256];
	sprintf((char*)tx_buff, "--> Test Test: started...\n\r");
	USART0_sendString(tx_buff);
	
	initCommonDataMgmt();
	
	#ifdef USE_FREE_RTOS
		
		terminal_tx_buffer = xMessageBufferCreate(512);
		
		// Create task.
		xTaskCreate(vCommunicationTask,	"uart",		configMINIMAL_STACK_SIZE+1024,	NULL, COMMUNICATION_TASK_PRIORITY,	NULL);
		xTaskCreate(vGpsTask,			"gps",		configMINIMAL_STACK_SIZE+512,	NULL, GPS_TASK_PRIORITY,			NULL);
		xTaskCreate(vEnvSensorTask,		"sensor",	configMINIMAL_STACK_SIZE+512,	NULL, ENV_SESNOR_TASK_PRIORITY,		NULL);
		xTaskCreate(vMotionTask,		"motion",	configMINIMAL_STACK_SIZE+1024,	NULL, MOTION_TASK_PRIORITY,			NULL);

		// Start scheduler.
		vTaskStartScheduler();

		return 0;
		
	#endif

}

/**************************************************************************//**
	* \fn static vApplicationIdleHook(void)
	*
	* \brief
	******************************************************************************/
void vApplicationIdleHook(void)
{

}
	
/**************************************************************************//**
	* \fn static vApplicationIdleHook(void)
	*
	* \brief
	******************************************************************************/
void vApplicationTickHook(void)
{

}

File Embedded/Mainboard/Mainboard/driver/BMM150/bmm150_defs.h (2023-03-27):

/**
* Copyright (c) 2020 Bosch Sensortec GmbH. All rights reserved.
*
* BSD-3-Clause
*
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
* 1. Redistributions of source code must retain the above copyright
*    notice, this list of conditions and the following disclaimer.
*
* 2. Redistributions in binary form must reproduce the above copyright
*    notice, this list of conditions and the following disclaimer in the
*    documentation and/or other materials provided with the distribution.
*
* 3. Neither the name of the copyright holder nor the names of its
*    contributors may be used to endorse or promote products derived from
*    this software without specific prior written permission.
*
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
* @file       bmm150_defs.h
* @date       2020-06-03
* @version    v2.0.0
*
*/

/*! \file bmm150_defs.h */

#ifndef _BMM150_DEFS_H
#define _BMM150_DEFS_H

/******************************************************************************/
/*! @name       Header includes                           */
/******************************************************************************/
#ifdef __KERNEL__
#include <linux/types.h>
#else
#include <stdint.h>
#include <stddef.h>
#endif

/******************************************************************************/
/*! @name       Common macros                         */
/******************************************************************************/
#ifdef __KERNEL__
#if (LONG_MAX) > 0x7fffffff
#define __have_long64  1
#elif (LONG_MAX) == 0x7fffffff
#define __have_long32  1
#endif
#endif

#if !defined(UINT8_C)
#define INT8_C(x)      x
#if (INT_MAX) > 0x7f
#define UINT8_C(x)     x
#else
#define UINT8_C(x)     x##U
#endif
#endif

#if !defined(UINT16_C)
#define INT16_C(x)     x
#if (INT_MAX) > 0x7fff
#define UINT16_C(x)    x
#else
#define UINT16_C(x)    x##U
#endif
#endif

#if !defined(INT32_C) && !defined(UINT32_C)
#if __have_long32
#define INT32_C(x)     x##L
#define UINT32_C(x)    x##UL
#else
#define INT32_C(x)     x
#define UINT32_C(x)    x##U
#endif
#endif

#if !defined(INT64_C) && !defined(UINT64_C)
#if __have_long64
#define INT64_C(x)     x##L
#define UINT64_C(x)    x##UL
#else
#define INT64_C(x)     x##LL
#define UINT64_C(x)    x##ULL
#endif
#endif

/*! @name C standard macros */
#ifndef NULL
#ifdef __cplusplus
#define NULL           0
#else
#define NULL           ((void *) 0)
#endif
#endif

/******************************************************************************/
/*! @name        Compiler switch macros Definitions                */
/******************************************************************************/
#ifndef BMM150_USE_FLOATING_POINT /*< Check if floating point (using BMM150_USE_FLOATING_POINT) is enabled */
#ifndef BMM150_USE_FIXED_POINT /*< If floating point is not enabled then enable BMM150_USE_FIXED_POINT */
#define BMM150_USE_FIXED_POINT
#endif
#endif

/******************************************************************************/
/*! @name        General Macro Definitions                */
/******************************************************************************/
/*! @name API success code */
#define BMM150_OK                                 INT8_C(0)

/*! @name To define TRUE or FALSE */
#define BMM150_TRUE                               UINT8_C(1)
#define BMM150_FALSE                              UINT8_C(0)

/*! @name API error codes */
#define BMM150_E_NULL_PTR                         INT8_C(-1)
#define BMM150_E_DEV_NOT_FOUND                    INT8_C(-2)
#define BMM150_E_INVALID_CONFIG                   INT8_C(-3)
#define BMM150_E_COM_FAIL                         INT8_C(-4)

/*! @name API warning codes */
#define BMM150_W_NORMAL_SELF_TEST_YZ_FAIL         INT8_C(1)
#define BMM150_W_NORMAL_SELF_TEST_XZ_FAIL         INT8_C(2)
#define BMM150_W_NORMAL_SELF_TEST_Z_FAIL          INT8_C(3)
#define BMM150_W_NORMAL_SELF_TEST_XY_FAIL         INT8_C(4)
#define BMM150_W_NORMAL_SELF_TEST_Y_FAIL          INT8_C(5)
#define BMM150_W_NORMAL_SELF_TEST_X_FAIL          INT8_C(6)
#define BMM150_W_NORMAL_SELF_TEST_XYZ_FAIL        INT8_C(7)
#define BMM150_W_ADV_SELF_TEST_FAIL               INT8_C(8)

/*! @name CHIP ID & SOFT RESET VALUES      */
#define BMM150_CHIP_ID                            UINT8_C(0x32)
#define BMM150_SET_SOFT_RESET                     UINT8_C(0x82)

/*! @name POWER MODE DEFINTIONS      */
#define BMM150_POWERMODE_NORMAL                   UINT8_C(0x00)
#define BMM150_POWERMODE_FORCED                   UINT8_C(0x01)
#define BMM150_POWERMODE_SLEEP                    UINT8_C(0x03)
#define BMM150_POWERMODE_SUSPEND                  UINT8_C(0x04)

/*! @name Power mode settings  */
#define BMM150_POWER_CNTRL_DISABLE                UINT8_C(0x00)
#define BMM150_POWER_CNTRL_ENABLE                 UINT8_C(0x01)

/*! @name I2C ADDRESS       */
#define BMM150_DEFAULT_I2C_ADDRESS                UINT8_C(0x10)
#define BMM150_I2C_ADDRESS_CSB_LOW_SDO_HIGH       UINT8_C(0x11)
#define BMM150_I2C_ADDRESS_CSB_HIGH_SDO_LOW       UINT8_C(0x12)
#define BMM150_I2C_ADDRESS_CSB_HIGH_SDO_HIGH      UINT8_C(0x13)
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

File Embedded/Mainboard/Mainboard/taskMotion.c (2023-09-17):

/*
 * taskEnvSensor.c
 *
 * Created: 24.03.2023 18:56:49
 *  Author: jakob
 */ 

#include <avr/io.h>
#include <avr/interrupt.h>
#include <util/delay.h>
#include <stdio.h>
#include <stdlib.h>
#include <string.h>
#include <avr/cpufunc.h>
#include <string.h>

#include "OS/freeRTOS/include/FreeRTOS.h"
#include "OS/freeRTOS/include/task.h"
#include "OS/freeRTOS/include/stream_buffer.h"
#include "OS/freeRTOS/include/message_buffer.h"

#include "commonOS.h"
#include "commonDriver.h"
#include "commonDataMgmt.h"

#include "driver/INA228/ina228.h"
#include "driver/PCA9685/pca9685.h"

#include "taskMotion.h"


// ********************************************************************************
// Macros and Defines
// ********************************************************************************


// ********************************************************************************
// Finctions
// ********************************************************************************
static int8_t setMotorParameter(uint8_t motorNr, uint16_t velocity, uint8_t direction, struct pca9685_dev *dev);

// ********************************************************************************
// Variables
// ********************************************************************************

struct ina228_dev	monitorMotor_0;
struct ina228_dev	monitorMotor_1;

struct pca9685_dev	pwmControl;

#define TASK_TIME			50				// ms
#define CONST_BACKWARD_CNT	10				//* TASK_TIME	// timeout
#define CONST_ROTATION_CNT	10				//* TASK_TIME	// timeout
#define CONST_STOP_CNT		2
#define CONST_ROTATION_DEG	45				// [Deg]
#define CONST_VELOCITY_HIGH 2000
#define CONST_VELOCITY_LOW	1000
#define CONST_MOWER_VEL		4000
#define CONST_DIST_LEVEL_1	1000			// [mm]
#define CONST_DIST_LEVEL_2	1000			// [mm]
#define CONST_DIST_LEVEL_3	800				// [mm]
#define CONST_DIST_LEVEL_4	400				// [mm]

enum stateMachine
{
	STATE_INIT,
	STATE_FORWARD,
	STATE_SLOW_FORWARD,
	STATE_BACKWARD,
	STATE_START_ROTATION,
	STATE_ROTATION,
	STATE_STOP,
	STATE_DISTANCE,
	STATE_WIRE,
	STATE_HOME,
	STATE_CHARGE,
	STATE_ERROR
};


/**************************************************************************//**
* \fn static void vUartTask(void* pvParameters)
*
* \brief
*
* \param[in]   pvParameters
******************************************************************************/
void vMotionTask(void* pvParameters)
{
	//static const char msg[] = "--> TASK vMotionTask: started...\n\r";
	//xMessageBufferSend(terminal_tx_buffer, msg, sizeof(msg), 0);

	uint8_t dev_addr_monitroMotor_0 = INA228_SLAVE_ADDRESS;
	monitorMotor_0.intf_ptr = &dev_addr_monitroMotor_0;
	monitorMotor_0.shunt_ADCRange = 0;
	monitorMotor_0.read = user_i2c_1_read;
	monitorMotor_0.write = user_i2c_1_write;
	monitorMotor_0.delay_us = user_delay_us;
	
	uint8_t dev_addr_monitroMotor_1 = INA228_SLAVE_ADDRESS + 1;
	monitorMotor_1.intf_ptr = &dev_addr_monitroMotor_1;
	monitorMotor_1.shunt_ADCRange = 0;
	monitorMotor_1.read = user_i2c_1_read;
	monitorMotor_1.write = user_i2c_1_write;
	monitorMotor_1.delay_us = user_delay_us;

	pwmControl.i2c_addr = PCA9685_I2C_ADDRESS(0, 0, 0, 1, 1, 1);
	pwmControl.read = user_i2c_1_read_pca;
	pwmControl.write = user_i2c_1_write_pca;
	pwmControl.delay_ms = user_delay_ms;

	ina228_init(&monitorMotor_0);
	//sprintf((char*)buffer, "--> TASK vMotionTask: TI INA228 [0] --> CHIP_ID: 0x%02X\n\r", monitorMotor_0.devID);
	//xMessageBufferSend(terminal_tx_buffer, buffer, sizeof(buffer), 500);

	ina228_init(&monitorMotor_1);
	//sprintf((char*)buffer, "--> TASK vMotionTask: TI INA228 [1] --> CHIP_ID: 0x%02X\n\r", monitorMotor_1.devID);
	//xMessageBufferSend(terminal_tx_buffer, buffer, sizeof(buffer), 500);

	pca9685_init(&pwmControl);
	//sprintf((char*)buffer, "--> TASK vMotionTask: PCA9685 INIT --> CHIP_ID: 0x%02X\n\r", pwmControl.chip_id);
	//xMessageBufferSend(terminal_tx_buffer, buffer, sizeof(buffer), 500);

	uint8_t collosionStatus = 0;
	uint16_t velocity_1 = 0;
	uint16_t velocity_2 = 0;
	uint16_t dir_1 = 0;
	uint16_t dir_2 = 0;
	uint16_t mowerMotorVel = 0;
	float voltage_0, voltage_1;
	float current_0, current_1;
	uint16_t counterCollosion = 0;
	uint16_t state = STATE_INIT;
	uint16_t state_old = STATE_INIT;
	
	uint16_t backward_time = 0;
	uint16_t rotation_time = 0;
	uint16_t stop_time = 0;
	
	int16_t t1 = 0;
	int16_t t2 = 0;
	int16_t d = 0;
	
	for ( ;; )
	{	
		state_old = state;
		ina228_voltage(&voltage_0, &monitorMotor_0);
		ina228_voltage(&voltage_1, &monitorMotor_1);
		ina228_current(&current_0, &monitorMotor_0);
		ina228_current(&current_1, &monitorMotor_1);

		glbRoboterData.motorCurrent[0] = (int16_t)(current_0 * 1);
		glbRoboterData.motorVoltage[0] = (int16_t)(voltage_0 * 1000);
		glbRoboterData.motorCurrent[1] = (int16_t)(current_1 * 1);
		glbRoboterData.motorVoltage[1] = (int16_t)(voltage_1 * 1000);

		glbRoboterData.sens_collosion_00 = PORTD_get_pin_level(SENSOR_COLLISION_00);
		glbRoboterData.sens_collosion_01 = PORTD_get_pin_level(SENSOR_COLLISION_01);
		glbRoboterData.sens_collosion_02 = PORTD_get_pin_level(SENSOR_COLLISION_02);
/*		
		if (glbRoboterData.errorNeigung == 1)
		{
			state = STATE_ERROR;
		}
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

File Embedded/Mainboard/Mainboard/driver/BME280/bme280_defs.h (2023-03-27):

/**
* Copyright (c) 2020 Bosch Sensortec GmbH. All rights reserved.
*
* BSD-3-Clause
*
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
* 1. Redistributions of source code must retain the above copyright
*    notice, this list of conditions and the following disclaimer.
*
* 2. Redistributions in binary form must reproduce the above copyright
*    notice, this list of conditions and the following disclaimer in the
*    documentation and/or other materials provided with the distribution.
*
* 3. Neither the name of the copyright holder nor the names of its
*    contributors may be used to endorse or promote products derived from
*    this software without specific prior written permission.
*
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
* @file       bme280_defs.h
* @date       2020-03-28
* @version    v3.5.0
*
*/

#ifndef BME280_DEFS_H_
#define BME280_DEFS_H_

/********************************************************/
/* header includes */
#ifdef __KERNEL__
#include <linux/types.h>
#include <linux/kernel.h>
#else
#include <stdint.h>
#include <stddef.h>
#endif

/********************************************************/
/*! @name       Common macros               */
/********************************************************/

#if !defined(UINT8_C) && !defined(INT8_C)
#define INT8_C(x)    S8_C(x)
#define UINT8_C(x)   U8_C(x)
#endif

#if !defined(UINT16_C) && !defined(INT16_C)
#define INT16_C(x)   S16_C(x)
#define UINT16_C(x)  U16_C(x)
#endif

#if !defined(INT32_C) && !defined(UINT32_C)
#define INT32_C(x)   S32_C(x)
#define UINT32_C(x)  U32_C(x)
#endif

#if !defined(INT64_C) && !defined(UINT64_C)
#define INT64_C(x)   S64_C(x)
#define UINT64_C(x)  U64_C(x)
#endif

/**@}*/
/**\name C standard macros */
#ifndef NULL
#ifdef __cplusplus
#define NULL         0
#else
#define NULL         ((void *) 0)
#endif
#endif

/********************************************************/

#ifndef BME280_64BIT_ENABLE /*< Check if 64-bit integer (using BME280_64BIT_ENABLE) is enabled */
#ifndef BME280_32BIT_ENABLE /*< Check if 32-bit integer (using BME280_32BIT_ENABLE) is enabled */
#define BME280_32BIT_ENABLE
#ifndef BME280_FLOAT_ENABLE /*< If any of the integer data types not enabled then enable BME280_FLOAT_ENABLE */
//#define BME280_FLOAT_ENABLE
#endif
#endif
#endif

#ifndef TRUE
#define TRUE                                      UINT8_C(1)
#endif
#ifndef FALSE
#define FALSE                                     UINT8_C(0)
#endif

/**
 * BME280_INTF_RET_TYPE is the read/write interface return type which can be overwritten by the build system.
 */
#ifndef BME280_INTF_RET_TYPE
#define BME280_INTF_RET_TYPE                      int8_t
#endif

/**
 * The last error code from read/write interface is stored in the device structure as intf_rslt.
 */
#ifndef BME280_INTF_RET_SUCCESS
#define BME280_INTF_RET_SUCCESS                   INT8_C(0)
#endif

/**\name I2C addresses */
#define BME280_I2C_ADDR_PRIM                      UINT8_C(0x76)
#define BME280_I2C_ADDR_SEC                       UINT8_C(0x77)

/**\name BME280 chip identifier */
#define BME280_CHIP_ID                            UINT8_C(0x60)

/**\name Register Address */
#define BME280_CHIP_ID_ADDR                       UINT8_C(0xD0)
#define BME280_RESET_ADDR                         UINT8_C(0xE0)
#define BME280_TEMP_PRESS_CALIB_DATA_ADDR         UINT8_C(0x88)
#define BME280_HUMIDITY_CALIB_DATA_ADDR           UINT8_C(0xE1)
#define BME280_PWR_CTRL_ADDR                      UINT8_C(0xF4)
#define BME280_CTRL_HUM_ADDR                      UINT8_C(0xF2)
#define BME280_CTRL_MEAS_ADDR                     UINT8_C(0xF4)
#define BME280_CONFIG_ADDR                        UINT8_C(0xF5)
#define BME280_DATA_ADDR                          UINT8_C(0xF7)

/**\name API success code */
#define BME280_OK                                 INT8_C(0)

/**\name API error codes */
#define BME280_E_NULL_PTR                         INT8_C(-1)
#define BME280_E_DEV_NOT_FOUND                    INT8_C(-2)
#define BME280_E_INVALID_LEN                      INT8_C(-3)
#define BME280_E_COMM_FAIL                        INT8_C(-4)
#define BME280_E_SLEEP_MODE_FAIL                  INT8_C(-5)
#define BME280_E_NVM_COPY_FAILED                  INT8_C(-6)

/**\name API warning codes */
#define BME280_W_INVALID_OSR_MACRO                INT8_C(1)

/**\name Macros related to size */
#define BME280_TEMP_PRESS_CALIB_DATA_LEN          UINT8_C(26)
#define BME280_HUMIDITY_CALIB_DATA_LEN            UINT8_C(7)
#define BME280_P_T_H_DATA_LEN                     UINT8_C(8)

/**\name Sensor power modes */
#define BME280_SLEEP_MODE                         UINT8_C(0x00)
#define BME280_FORCED_MODE                        UINT8_C(0x01)
#define BME280_NORMAL_MODE                        UINT8_C(0x03)

/**\name Macro to combine two 8 bit data's to form a 16 bit data */
#define BME280_CONCAT_BYTES(msb, lsb)             (((uint16_t)msb << 8) | (uint16_t)lsb)
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

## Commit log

2022-10-18 Schaltplan hinzugefügt. Erster entwurf
    [main_board.brd, main_board.sch]
2022-10-21 main_board.brd - Layout
    [main_board.brd, main_board.sch]
2022-10-31 layout update
    [Motor.kicad_sch, RoboticLawnMower.kicad_pcb, RoboticLawnMower.kicad_sch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]
2022-11-01 schaltplan und layout
    [Motor.kicad_sch, RoboticLawnMower.kicad_pcb, RoboticLawnMower.kicad_sch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]
2023-01-21 bild hinzugefügt.
    [RoboticLawnMower.kicad_pcb, RoboticLawnMower.kicad_sch, uC.kicad_sch]
2023-02-04 Schaltplan und Layout änderung
    [RoboticLawnMower.kicad_pcb, RoboticLawnMower.kicad_sch, charge.kicad_sch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]
2023-02-08 Schaltplan & Layout Änderung
    [Motor.kicad_sch, RoboticLawnMower.kicad_pcb, RoboticLawnMower.kicad_sch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]
2023-02-11 Layout ready add gerber file
    [RoboticLawnMower.kicad_pcb, RoboticLawnMower.kicad_sch, gps.kicad_sch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]
2023-02-28 kleine Änderung
    [IO_Funktion_Beschreibung.xlsx]
2023-02-28 projekt aufgeräumt
    [PinMapping.xlsx, main_board.brd, main_board.sch]
2023-03-01 add driver - BMM150 - INA228
2023-03-07 bugFix driver BMI160 BMM150
    [bmm150_defs.h, main.c]
2023-03-07 bug fix bmm150 bmi160
    [adc.c, main.c]
2023-03-11 add pca9685 driver
2023-03-12 add gps/nmea driver
2023-03-19 add TMAG5273 driver add lwgps driver
2023-07-30 save files with KiCad 7.0
    [Motor.kicad_sch, RoboticLawnMower.kicad_sch, comfort.kicad_sch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]
2023-09-11 implement driver: - VL53L1X
2023-09-12 Motor L und R läuft Abstandsensor läuft Kollision läuft
2023-10-08 add perimeter sender
    [POWER.kicad_sch, POWER_OUTPUT.kicad_sch, Perimeter Sender.kicad_pcb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]
2024-06-02 Redesign: - Controller - I2C pinning geändert - uvm
    [Motor.kicad_sch, POWER.kicad_sch, POWER_OUTPUT.kicad_sch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]
2024-06-02 Schaltplan hinzugefügt RS485 Lib hinzugefügt
    [RS485.kicad_sch]
2024-06-02 hinterrad 3d model
    [rearWheel.stl]
2024-06-03 änderung
    [rearWheel_6xSpoke.stl]
2025-04-07 change µC to STM32H573
    [IO_Funktion_Beschreibung.xlsx, Motor.kicad_sch, RS485.kicad_sch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]
2025-04-11 Layout fertig, Gerber-Datei muss noch erzeugt werden.
    [Motor.kicad_sch, RoboticLawnMower.kicad_pcb, uC.kicad_sch]
2025-04-14 Levelshift für MotorSignal zum µC
    [Motor.kicad_sch, RoboticLawnMower.kicad_pcb, uC.kicad_sch]
2025-04-14 gerberdaten erzeugt
